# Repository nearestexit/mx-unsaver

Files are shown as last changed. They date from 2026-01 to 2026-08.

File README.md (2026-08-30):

# mx-unsaver

Custom keyboard and numpad inspired by vintage Cherry keyboards and the [IBM "Unsaver"](https://sharktastica.co.uk/topics/keyboard-dictionary/unsaver).
Designed in Onshape and KiCad.
Powered by [QMK](https://github.com/qmk/qmk_firmware).

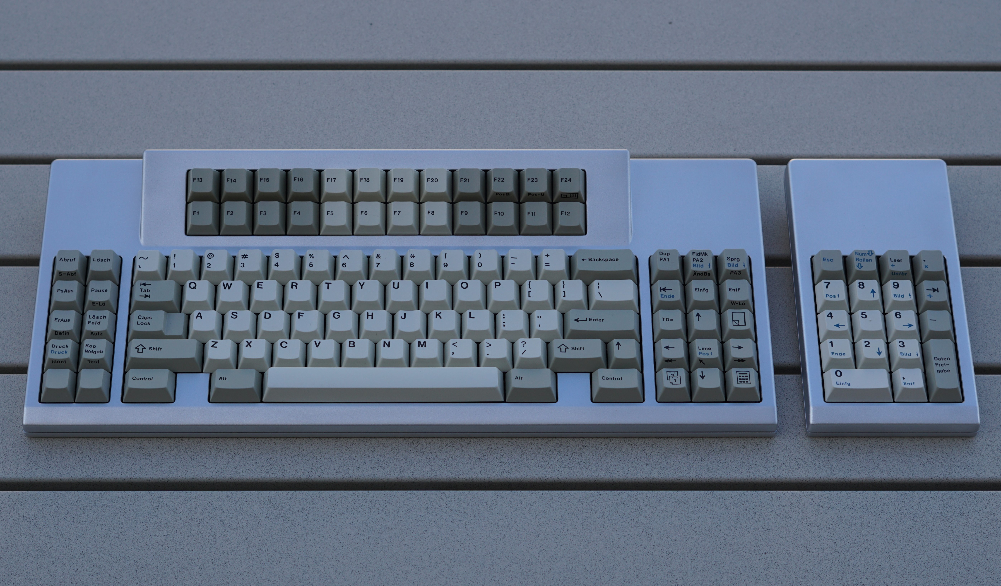
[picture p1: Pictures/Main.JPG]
Front


## Overview
- Side profile and shape inspired by the Cherry G80-5700 and G80-1800
- PCB Top-Mount
- Integrated USB Hub with 1x USB-C Upstream port and 2x USB-C and 2x USB-A Downstream ports
- Brass through-weight

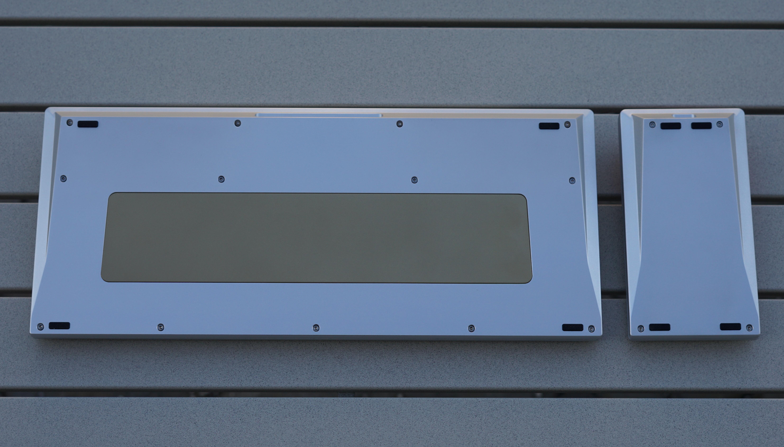
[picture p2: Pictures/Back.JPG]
Back


Combo1

**Case Source (Onshape):** https://cad.onshape.com/documents/1d9e79a61d42e7395c429f47/w/28912f958105e1c831f67a9e/e/537bd51b2d234361e6d6eea3

Combo2

## PCB
The PCB supports ISO and ANSI. Unfortunately, due to an oversight, the Case only supports ANSI enter. It could be relatively easily modified to support ISO enter.
I ordered single bare PCBs from EuroCircuits and OSHPark and hand-soldered the components, so I do not have JLCPCB production files available.

**Important: The PCB has the words "Made In Germany" printed on it. This is because it was actually manufactured in Germany. If you choose to have it manufactured in China, please remove this logo from the PCB.**

PCB

## Bill of Materials

| Item  | Quantity | Link |
| --- | --- | --- |
| M2x4x3mm Hex Standoff | 2 | https://www.ebay.com/itm/355663469861?var=624766479032 |
| M2x3x4mm Wafer head Screw | 2 | https://www.ebay.com/itm/355676691340?var=624776776427 |
| Feet | 8 | https://cannonkeys.com/products/akb-feet |
| M2.5x8mm BHCS | 57 | https://mcmaster.com/92095A459 |
| M2.5x6mm SHCS | 14 | https://mcmaster.com/91292A010 |
| M2.5x10mm SHCS | 7 | https://mcmaster.com/91292A014 |
| M2.5x25mm SHCS | 6 | https://mcmaster.com/91292A036 |
| M2.5x20mm SHCS | 4 | https://mcmaster.com/91292A019 |
| M3x6mm Countersunk | 5 | https://mcmaster.com/92125A126 |
| M3x8mm Countersunk | 9 | https://mcmaster.com/92125A128 |
| 1:1 JST-SH Cable (50mm) | 3 | https://www.digikey.com/en/products/detail/adafruit-industries-llc/4210/10230021 |
| FPC Cable (50.8mm) | 1 | https://www.digikey.com/en/products/detail/molex/0151660207/3281088 |

## USB Hub
The USB Hub utilizes two [FE1.1S](https://www.digikey.ca/datasheets/production/1879844/1/FE1-1s-Datasheet.html) USB 2.0 HS Hub chips in series. It can deliver a total of 400mA downstream (the keyboard is assumed to use 100mA).

## Firmware

A QMK .bin file is provided for flashing, as well as QMK source files.

Unsaver

(The original Unsaver in this picture is not for sale.)

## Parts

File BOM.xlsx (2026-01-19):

Item | Qty | Part number | Manufacturer | Ordered | Note
Top Case | 1 |  | Gaojie | Yes
Bottom Case | 1 |  | Gaojie | Yes
Top Case (Numpad) | 1 |  | Gaojie | Yes
Bottom Case (Numpad) | 1 |  | Gaojie | Yes
Weight | 1 |  | Gaojie | Yes
PCB Mounting Block | 19 |  | Gaojie | Yes
MCU Cover | 1 |  | Ponoko | Yes
MCU Cover Standoff | 2 | https://www.ebay.com/itm/355663469861?var=624766479032 | Ebay | Yes
MCU Cover Screw | 2 | https://www.ebay.com/itm/355676691340?var=624776776427 | Ebay | Yes
Feet | 8 | https://cannonkeys.com/products/akb-feet | Cannonkeys | Yes
PCB Screw - M2.5x8mm BHCS | 57 | 92095A459 | McMaster | Yes
DB + Hub Screw - M2.5x6mm SHCS | 14 | 91292A010 | McMaster | Yes
Case Screw - Front - M2.5x10mm SHCS | 7 | 91292A014 | McMaster | N/A
Case Screw - Back - M2.5x25mm SHCS | 6 | 91292A036 | McMaster | Yes
Case Screw - Middle - M2.5x20mm SHCS | 4 | 91292A019 | McMaster | N/A
Weight Screw - short - M3x6mm CS | 5 | 92125A126 | McMaster | N/A
Weight Screw - long - M3x8mm CS | 9 | 92125A128 | McMaster | N/A
Main PCB | 1 |  | Eurocircuits | Yes
Numpad PCB | 1 |  | Eurocircuits | Yes
F-Row PCB | 1 |  | Eurocircuits | Yes
Numpad Daughterboard | 1 |  | OSHpark | Yes
USB-A Hub PCB | 1 |  | OSHpark | Yes
USB-C Hub PCB | 1 |  | OSHpark | Yes
1:1 JST-SH Cable (50mm) | 3 |  | Digikey | Yes
Ribbon cable (50mm) | 1 |  | Digikey | Yes

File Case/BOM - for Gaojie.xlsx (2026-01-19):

Item | Quantity | Material | Surface Treatment | Color
Top Case | 1 | 6063 Aluminum | Bead blast, anodize | Silver
Bottom Case | 1 | 6063 Aluminum | Bead blast, anodize | Silver
Top Case - Numpad | 1 | 6063 Aluminum | Bead blast, anodize | Silver
Bottom Case - Numpad | 1 | 6063 Aluminum | Bead blast, anodize | Silver
Weight | 1 | Brass | Bead blast, clear coat
PCB Mount Block | 20 | Polycarbonate (PC) |  | Clear

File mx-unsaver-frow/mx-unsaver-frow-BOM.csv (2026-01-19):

Reference | Value | Datasheet | Footprint | Qty | DNP | Digikey
D1 | LED_NUM | ~ | mx-unsaver:LED_MX_3mm_Offset_Flipped | 1 |  | 67-1058-ND
D22,D23,D24,D25,D26,D42,D43,D44,D45,D46,D62,D63,D64,D65,D66,D82,D83,D84,D85,D91,D102,D103,D104,D105 | D_Small | ~ | mx-unsaver:D_SOD-123_ShiftedSilkscreen | 24 |  | 1N4148W-FDICT-ND
J2 | Conn_01x20_MountingPin | ~ | mx-unsaver:CONN-SMD_20P-P0.50_10051922-2010ELF | 1 |  | 609-10051922-2010ELFCT-ND
MX23,MX24,MX25,MX26,MX27,MX43,MX44,MX45,MX46,MX47,MX63,MX64,MX65,MX66,MX67,MX83,MX84,MX85,MX86,MX92,MX107,MX108,MX109,MX110 | MX_SW_solder | ~ | mx-unsaver:SW_MX_1u_PCBMount | 24
R1 | 1k | ~ | Resistor_SMD:R_0805_2012Metric | 1 |  | P1.0KDACT-ND

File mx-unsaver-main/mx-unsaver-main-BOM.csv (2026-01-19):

Reference | Value | Datasheet | Footprint | Qty | DNP | Digikey
C1,C2,C5,C7 | 100n | ~ | Capacitor_SMD:C_0603_1608Metric | 4 |  | 311-1088-1-ND
C3,C8,C9 | 1u | ~ | Capacitor_SMD:C_0805_2012Metric | 3 |  | 1276-1029-1-ND
C4,C6 | 4.7u | ~ | Capacitor_SMD:C_0603_1608Metric | 2 |  | 1276-1784-1-ND
D1,D2,D3,D4,D5,D6,D7,D8,D9,D10,D11,D12,D13,D14,D15,D16,D17,D18,D19,D20,D26,D27,D28,D29,D30,D31,D32,D33,D34,D35,D36,D37,D38,D46,D47,D48,D49,D50,D51,D52,D53,D54,D55,D56,D57,D58,D59,D60,D67,D68,D69,D74,D75,D76,D77,D79,D80,D81,D82,D93,D94,D95,D96,D97,D102,D103,D104,D105,D106,D107,D108,D109,D110,D112,D120,D121,D122,D123,D124,D125,D126,D127,D128,D129,D130,D131,D132,D133,D134 | D_Small | ~ | mx-unsaver:D_SOD-123_ShiftedSilkscreen | 89 |  | 1N4148W-FDICT-ND
D71 | LED_LAYER2 | ~ | mx-unsaver:LED_MX_3mm_Offset_Flipped | 1 |  | 67-1058-ND
D72 | LED_LAYER3 | ~ | mx-unsaver:LED_MX_3mm_Offset_Flipped | 1 |  | 67-1058-ND
D73 | LED_LAYER4 | ~ | mx-unsaver:LED_MX_3mm_Offset_Flipped | 1 |  | 67-1058-ND
D78 | LED_CAPS2 | ~ | mx-unsaver:LED_MX_3mm_Offset_Flipped | 1 |  | 67-1058-ND
D86 | LED_CAPS1 | ~ | mx-unsaver:LED_MX_3mm_Offset | 1 |  | 67-1058-ND
D87 | LED_LAYER5 | ~ | mx-unsaver:LED_MX_3mm_Offset_Flipped | 1 |  | 67-1058-ND
D135 | LED_NUM | ~ | mx-unsaver:LED_MX_3mm_Offset_Flipped | 1 |  | 67-1058-ND
D136 | LED_SCLK | ~ | mx-unsaver:LED_MX_3mm_Offset_Flipped | 1 |  | 67-1058-ND
D137 | LED_LAYER1 | ~ | mx-unsaver:LED_MX_3mm_Offset_Flipped | 1 |  | 67-1058-ND
G1,G2 | MadeInGermany |  | mx-unsaver:MadeInGermany | 2
J1,J2 | Conn_01x02 | ~ | mx-unsaver:PinHeader_1x02_P2.54mm_BOOT | 2
J3 | Conn_01x04_MountingPin | ~ | Connector_JST:JST_SH_SM04B-SRSS-TB_1x04-1MP_P1.00mm_Horizontal | 1 |  | 455-SM04B-SRSS-TBCT-ND
J4,J5 | Conn_01x01 | ~ | mx-unsaver:PinHeader_1x01_P2.54mm | 2
J6 | Conn_01x20_MountingPin | ~ | mx-unsaver:CONN-SMD_20P-P0.50_10051922-2010ELF | 1 |  | 609-10051922-2010ELFCT-ND
MX1,MX2,MX3,MX4,MX5,MX6,MX7,MX8,MX9,MX10,MX11,MX12,MX13,MX14,MX15,MX16,MX17,MX18,MX19,MX20,MX26,MX27,MX28,MX29,MX30,MX31,MX32,MX33,MX34,MX35,MX36,MX37,MX38,MX46,MX47,MX48,MX49,MX50,MX51,MX52,MX53,MX54,MX55,MX56,MX57,MX58,MX59,MX60,MX67,MX68,MX69,MX71,MX72,MX73,MX74,MX75,MX76,MX77,MX78,MX85,MX86,MX87,MX88,MX89,MX91,MX92,MX93,MX94,MX95,MX96,MX97,MX98,MX99,MX100,MX106,MX107,MX108,MX109,MX110,MX111,MX112,MX113,MX114,MX115,MX116,MX117,MX118,MX119,MX120,MX121,MX122,MX123,MX124,MX125,MX126,MX127 | MX_SW_solder | ~ | -- mixed values -- | 96
R1 | 10k | ~ | Resistor_SMD:R_0805_2012Metric | 1 |  | RMCF0805FT10K0CT-ND
R2,R3,R4,R6,R8,R17,R18,R19 | 1k | ~ | Resistor_SMD:R_0805_2012Metric | 8 |  | P1.0KDACT-ND
S1,S2,S3,S4,S5,S6,S7 | MX_stab |  | -- mixed values -- | 7
U1 | STM32F072CBTx | https://www.st.com/resource/en/datasheet/stm32f072cb.pdf | Package_QFP:LQFP-48_7x7mm_P0.5mm | 1
U2 | XC6206PxxxMR | https://www.torexsemi.com/file/xc6206/XC6206.pdf | Package_TO_SOT_SMD:SOT-23-3 | 1 |  | 893-XC6206P332MR-GCT-ND

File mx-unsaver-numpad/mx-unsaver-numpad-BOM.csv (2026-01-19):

Reference | Value | Datasheet | Footprint | Qty | DNP | Digikey
C1,C2,C5,C7 | 100n | ~ | Capacitor_SMD:C_0603_1608Metric | 4 |  | 311-1088-1-ND
C3,C8,C9 | 1u | ~ | Capacitor_SMD:C_0805_2012Metric | 3 |  | 1276-1029-1-ND
C4,C6 | 4.7u | ~ | Capacitor_SMD:C_0603_1608Metric | 2 |  | 1276-1784-1-ND
D1 | LED_NUM | ~ | mx-unsaver:LED_MX_3mm_Offset_Flipped | 1 |  | 67-1058-ND
J1,J2 | Conn_01x01 | ~ | mx-unsaver:PinHeader_1x01_P2.54mm | 2
J3,J4 | Conn_01x02 | ~ | mx-unsaver:PinHeader_1x02_P2.54mm_BOOT | 2
J5 | Conn_01x04_MountingPin | ~ | Connector_JST:JST_SH_SM04B-SRSS-TB_1x04-1MP_P1.00mm_Horizontal | 1 |  | 455-SM04B-SRSS-TBCT-ND
MX1,MX2,MX3,MX4,MX5,MX6,MX7,MX8,MX9,MX10,MX11,MX12,MX13,MX14,MX15,MX16,MX17,MX18,MX19,MX20,MX21,MX22,MX23 | MX_SW_solder | ~ | -- mixed values -- | 23
R1 | 10k | ~ | Resistor_SMD:R_0805_2012Metric | 1 |  | RMCF0805FT10K0CT-ND
R2 | 1k | ~ | Resistor_SMD:R_0805_2012Metric | 1 |  | P1.0KDACT-ND
S1,S2,S3 | MX_stab |  | mx-unsaver:STAB_MX_2u_FixedDistance | 3
U1 | STM32F072CBTx | https://www.st.com/resource/en/datasheet/stm32f072cb.pdf | Package_QFP:LQFP-48_7x7mm_P0.5mm | 1
U2 | XC6206PxxxMR | https://www.torexsemi.com/file/xc6206/XC6206.pdf | Package_TO_SOT_SMD:SOT-23-3 | 1 |  | 893-XC6206P332MR-GCT-ND

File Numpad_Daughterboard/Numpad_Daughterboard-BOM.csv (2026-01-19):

Reference | Value | Datasheet | Footprint | Qty | DNP | Digikey
F1 | SMD0805-050-16V | ~ | Fuse:Fuse_1206_3216Metric | 1 |  | 18-1206L050/24WRCT-ND
J1 | USB_C_Receptacle_USB2.0_16P | https://www.usb.org/sites/default/files/documents/usb_type-c.zip | mx-unsaver:PHOENIX_1332645 | 1 |  | 277-1332645CT-ND
J2 | Conn_01x04_MountingPin | ~ | Connector_JST:JST_SH_SM04B-SRSS-TB_1x04-1MP_P1.00mm_Horizontal | 1 |  | 455-SM04B-SRSS-TBCT-ND
R1,R2 | 5.1k | ~ | Capacitor_SMD:C_0603_1608Metric_Pad1.08x0.95mm_HandSolder | 2 |  | P5.10KHCT-ND
U1 | SRV05-4 | http://www.onsemi.com/pub/Collateral/SRV05-4-D.PDF | PCM_marbastlib-various:SOT-23-6-routable | 1 |  | 5399-SRV05-4CT-ND

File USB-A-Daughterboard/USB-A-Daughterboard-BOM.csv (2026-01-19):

Reference | Value | Datasheet | Footprint | Qty | DNP | Digikey
C1,C2 | 33p | ~ | Capacitor_SMD:C_0603_1608Metric | 2 |  | 1276-1070-1-ND
C3,C4,C11,C12,C13 | 100n | ~ | Capacitor_SMD:C_0603_1608Metric | 5 |  | 311-1088-1-ND
C5,C6 | 10u | ~ | Capacitor_SMD:C_0603_1608Metric | 2 |  | 1276-1192-1-ND
C7,C8 | 100u | ~ | Capacitor_SMD:C_1206_3216Metric | 2 |  | 490-GRM31CR60J107KEA8LCT-ND
C9,C10 | 1u | ~ | Capacitor_SMD:C_0603_1608Metric | 2 |  | 1276-6524-1-ND
D1,D2,D3,D4 | LED_Small | ~ | LED_SMD:LED_0603_1608Metric | 4 |  | 2007-BL-HJC36G-AV-TRBCT-ND
F1 | SMD0805-050-16V | ~ | Fuse:Fuse_1206_3216Metric | 1 |  | 18-1206L050/24WRCT-ND
J1,J2,J5 | USB_C_Receptacle_USB2.0_16P | https://www.usb.org/sites/default/files/documents/usb_type-c.zip | mx-unsaver:PHOENIX_1332645 | 3 |  | 277-1332645CT-ND
J3,J4 | Conn_01x04 | ~ | Connector_JST:JST_SH_SM04B-SRSS-TB_1x04-1MP_P1.00mm_Horizontal | 2 |  | 455-SM04B-SRSS-TBCT-ND
R1 | 2.7k | ~ | Resistor_SMD:R_0603_1608Metric | 1 |  | RMCF0603FT2K70
R2,R3,R4,R5,R10 | 10k | ~ | Resistor_SMD:R_0603_1608Metric | 5 |  | 311-10.0KHRCT-ND
R6,R7,R9 | 510 | ~ | Resistor_SMD:R_0603_1608Metric | 3 |  | RR08P510DCT-ND
R8 | 1k | ~ | Resistor_SMD:R_0603_1608Metric | 1 |  | RMCF0603FT1K00CT-ND
R11,R12 | 33k | ~ | Resistor_SMD:R_0603_1608Metric | 2 |  | 311-33.0KHRCT-ND
R13,R14 | 5.1k | ~ | Resistor_SMD:R_0603_1608Metric | 2 |  | P5.10KHCT-ND
R15,R16,R17,R18 | 56k | ~ | Resistor_SMD:R_0603_1608Metric | 4 |  | P56KGCT-ND
TP1,TP2,TP3 | TestPoint_Small | ~ | TestPoint:TestPoint_THTPad_D1.0mm_Drill0.5mm | 3
U1 | FE1.1s-BSOP28BCN | https://www.lcsc.com/datasheet/C9359.pdf | Package_SO:SSOP-28_3.9x9.9mm_P0.635mm | 1
U2,U3,U4,U5,U6 | SRV05-4 | http://www.onsemi.com/pub/Collateral/SRV05-4-D.PDF | PCM_marbastlib-various:SOT-23-6-routable | 5 |  | 5399-SRV05-4CT-ND
U7 | TPS2552DBVR |  | Package_TO_SOT_SMD:SOT-23-6 | 1
Y1 | Crystal_GND24 | ~ | Crystal:Crystal_SMD_3225-4Pin_3.2x2.5mm | 1 |  | XC1810CT-ND

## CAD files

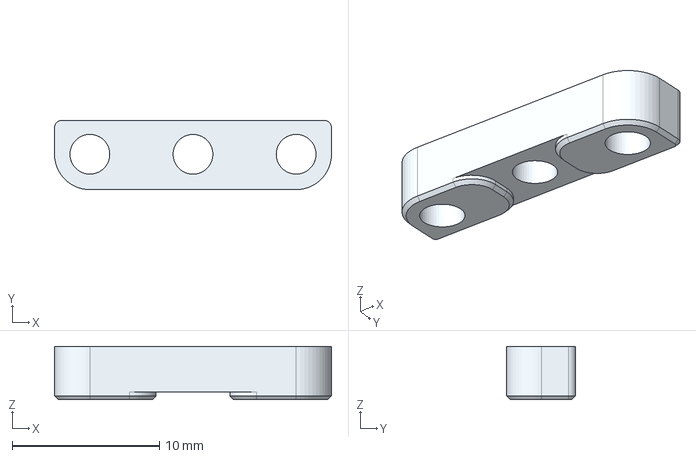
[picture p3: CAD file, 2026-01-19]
Case/STEP/PCB Mount Block.step
18.8 x 4.70 x 3.60 mm

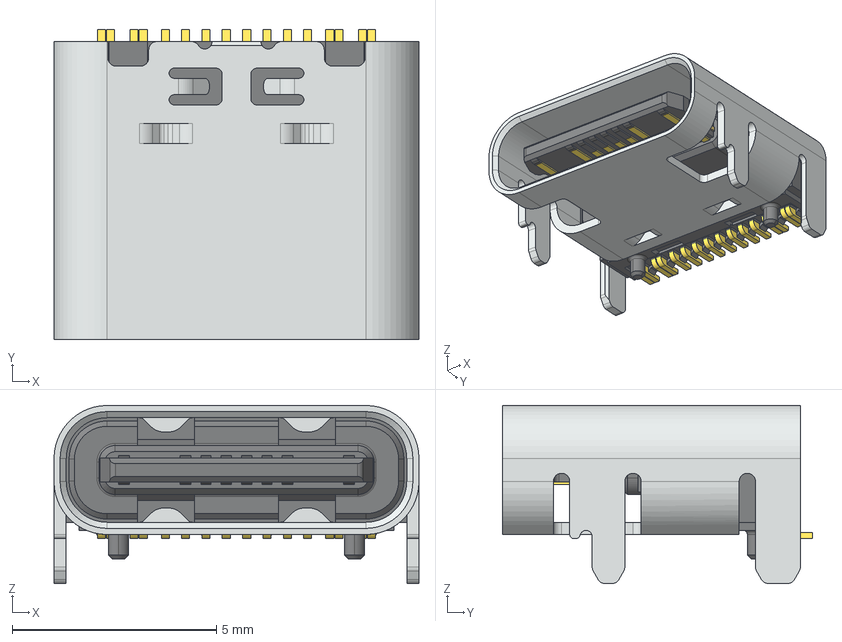
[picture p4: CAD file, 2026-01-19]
Component Datasheets & Models/pxc_1332645_00_00_CUC-USB3-1-J1ST-AH-UCF-SMD_3D.stp
8.94 x 7.60 x 4.36 mm

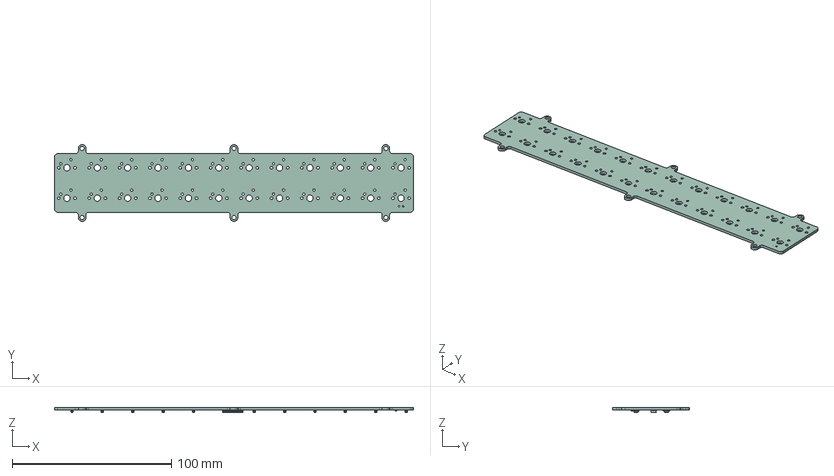
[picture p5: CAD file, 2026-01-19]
mx-unsaver-frow/mx-unsaver-frow.step
225.2 x 48.2 x 2.92 mm
D_SOD_123 x 24
R_0805_2012Metric
P10051922_2010ELF
mx-unsaver-frow_PCB

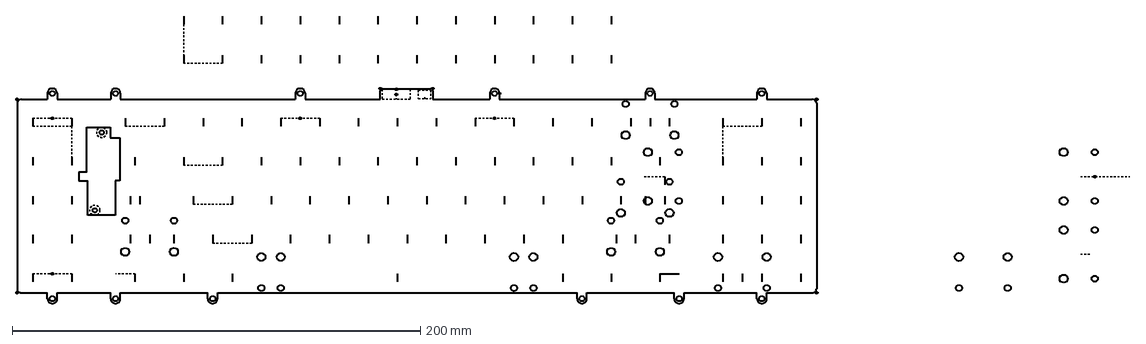
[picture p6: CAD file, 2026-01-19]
mx-unsaver-main/PCB Layout.dxf
545.9 x 140.9 mm

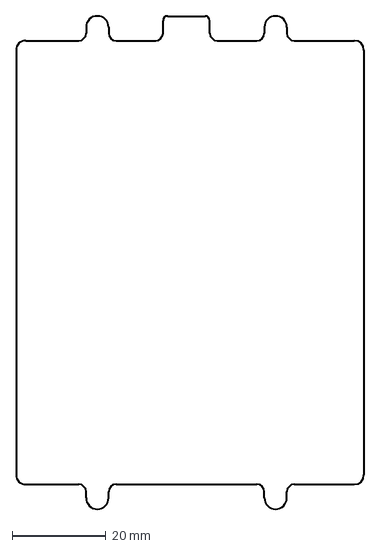
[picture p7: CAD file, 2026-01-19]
mx-unsaver-numpad/Numpad PCB Edge.cuts.dxf
74.3 x 105.4 mm

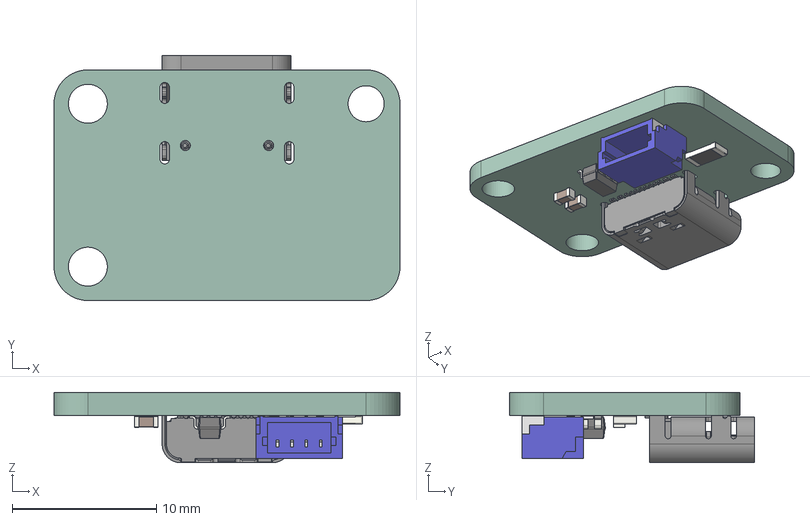
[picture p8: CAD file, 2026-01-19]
Numpad_Daughterboard/Numpad_Daughterboard.step
24.0 x 17.0 x 4.89 mm
C_0603_1608Metric x 2
CUC-USB3.1-J1ST-AH_UCF-SMD
SOT_23_6
SM04B-SRSS
Fuse_1206_3216Metric
Numpad_Daughterboard_PCB

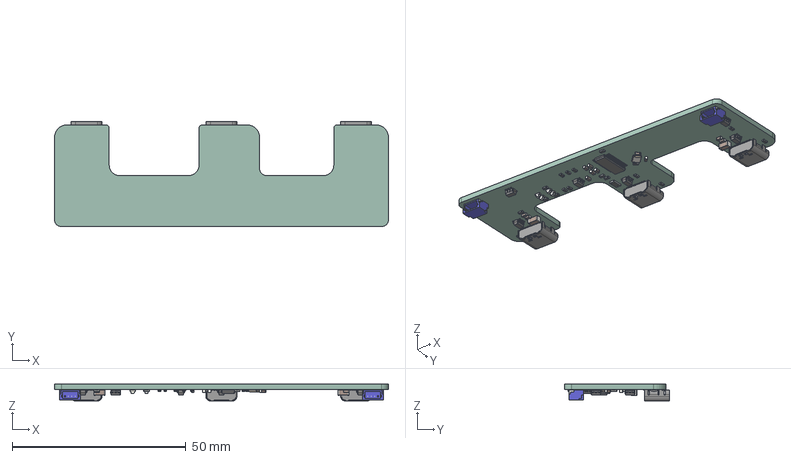
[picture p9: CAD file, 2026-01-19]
USB-A-Daughterboard/USB-A-Daughterboard.step
96.1 x 30.3 x 4.89 mm
R_0603_1608Metric x 18
SOT_23_6 x 6
SM04B-SRSS x 2
C_0603_1608Metric x 11
CUC-USB3.1-J1ST-AH_UCF-SMD x 3
C_1206_3216Metric x 2
Fuse_1206_3216Metric
SSOP_28_39x99mm_P0635mm
LED_0603_1608Metric x 4
Crystal_SMD_3225-4Pin_3.2x2.5mm
USB-A-Daughterboard_PCB

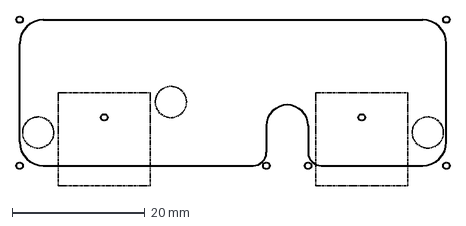
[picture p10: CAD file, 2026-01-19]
USBHubV3/USB-A PCB Layout.dxf
65.3 x 25.5 mm

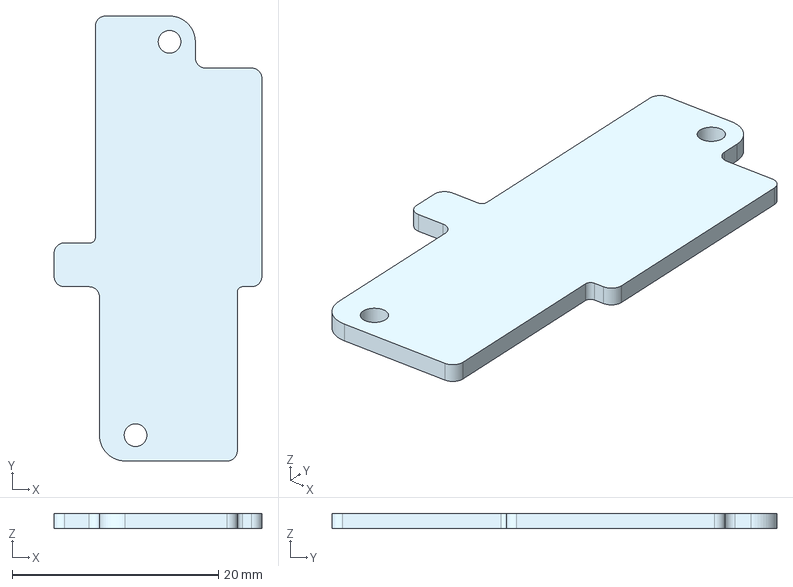
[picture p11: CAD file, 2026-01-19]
Case/STEP/MCU Cover.step
20.2 x 43.1 x 1.50 mm

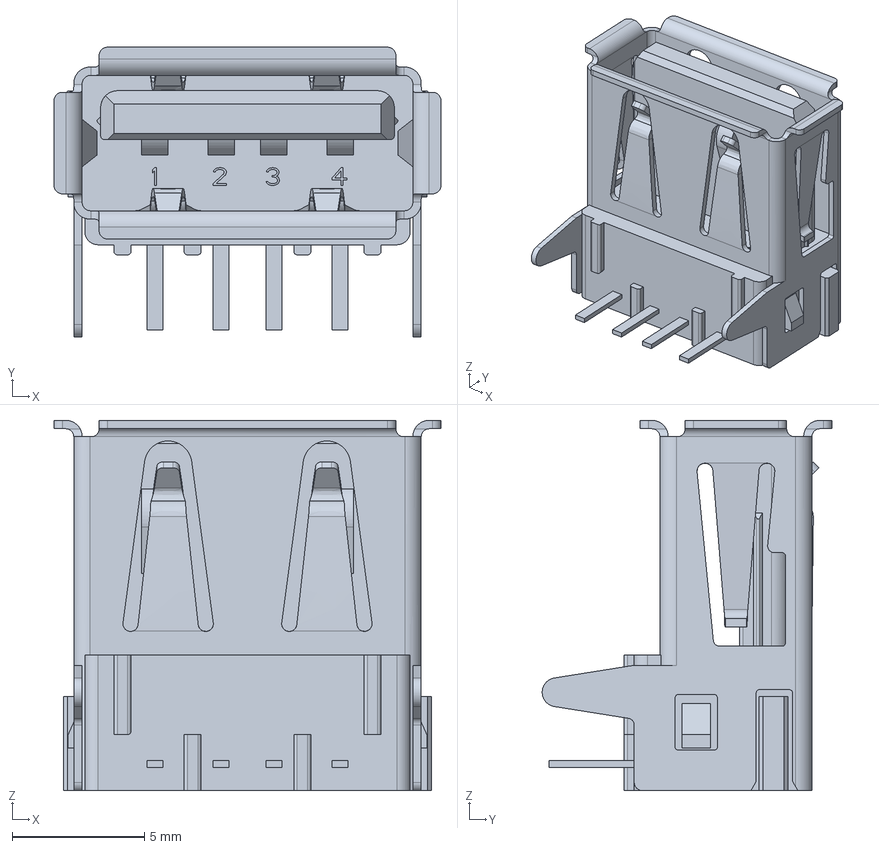
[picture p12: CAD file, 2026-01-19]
Component Datasheets & Models/c-6364372-2-o-3d.stp
14.6 x 10.9 x 14.0 mm

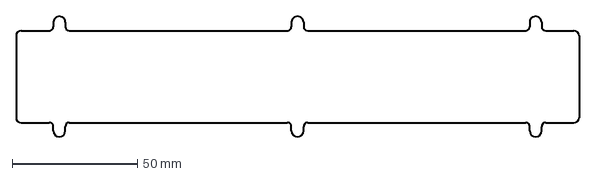
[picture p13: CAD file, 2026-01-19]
mx-unsaver-frow/F-Row PCB Edge.Cuts.dxf
225.2 x 48.3 mm

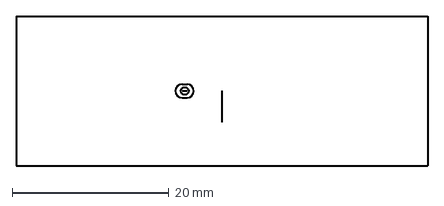
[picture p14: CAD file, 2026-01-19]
mx-unsaver-main/Drawing - RShift.dxf
52.4 x 19.0 mm

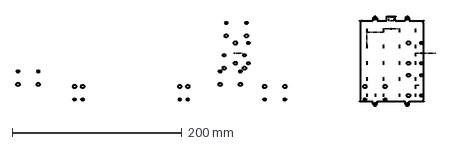
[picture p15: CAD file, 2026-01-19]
mx-unsaver-numpad/Numpad PCB Layout.dxf
494.1 x 106.0 mm

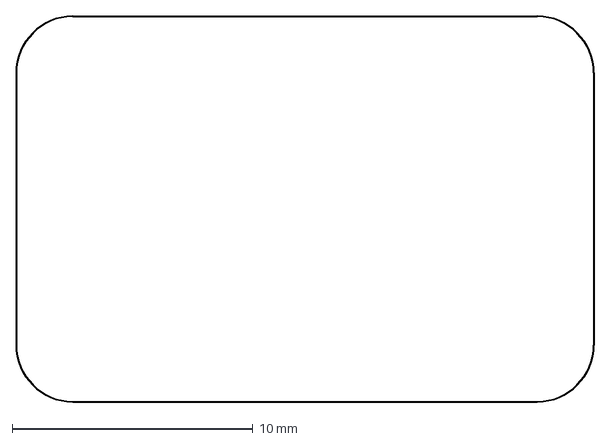
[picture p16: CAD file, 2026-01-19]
Numpad_Daughterboard/Numpad DB Edge.Cuts.dxf
24.0 x 16.0 mm

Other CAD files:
USBHubV3/USBHubV3.step
Case/STEP/Bottom Case.step
mx-unsaver-frow/F-Row PCB Layout.dxf
mx-unsaver-main/Drawing - LShift.dxf
Case/STEP/Bottom Case - Numpad.step
Case/STEP/Top Case - Numpad.step
Case/STEP/Top Case.step
Case/STEP/Weight.step
Numpad_Daughterboard/Numpad DB Layout.dxf
USBHubV3/USB-A PCB Edge.Cuts.dxf
mx-unsaver-main/Drawing - Enter.dxf
mx-unsaver-main/Drawing - Split Backspace Slots.dxf
mx-unsaver-main/PCB Edge.cuts.dxf
mx-unsaver-numpad/mx-unsaver-numpad.step

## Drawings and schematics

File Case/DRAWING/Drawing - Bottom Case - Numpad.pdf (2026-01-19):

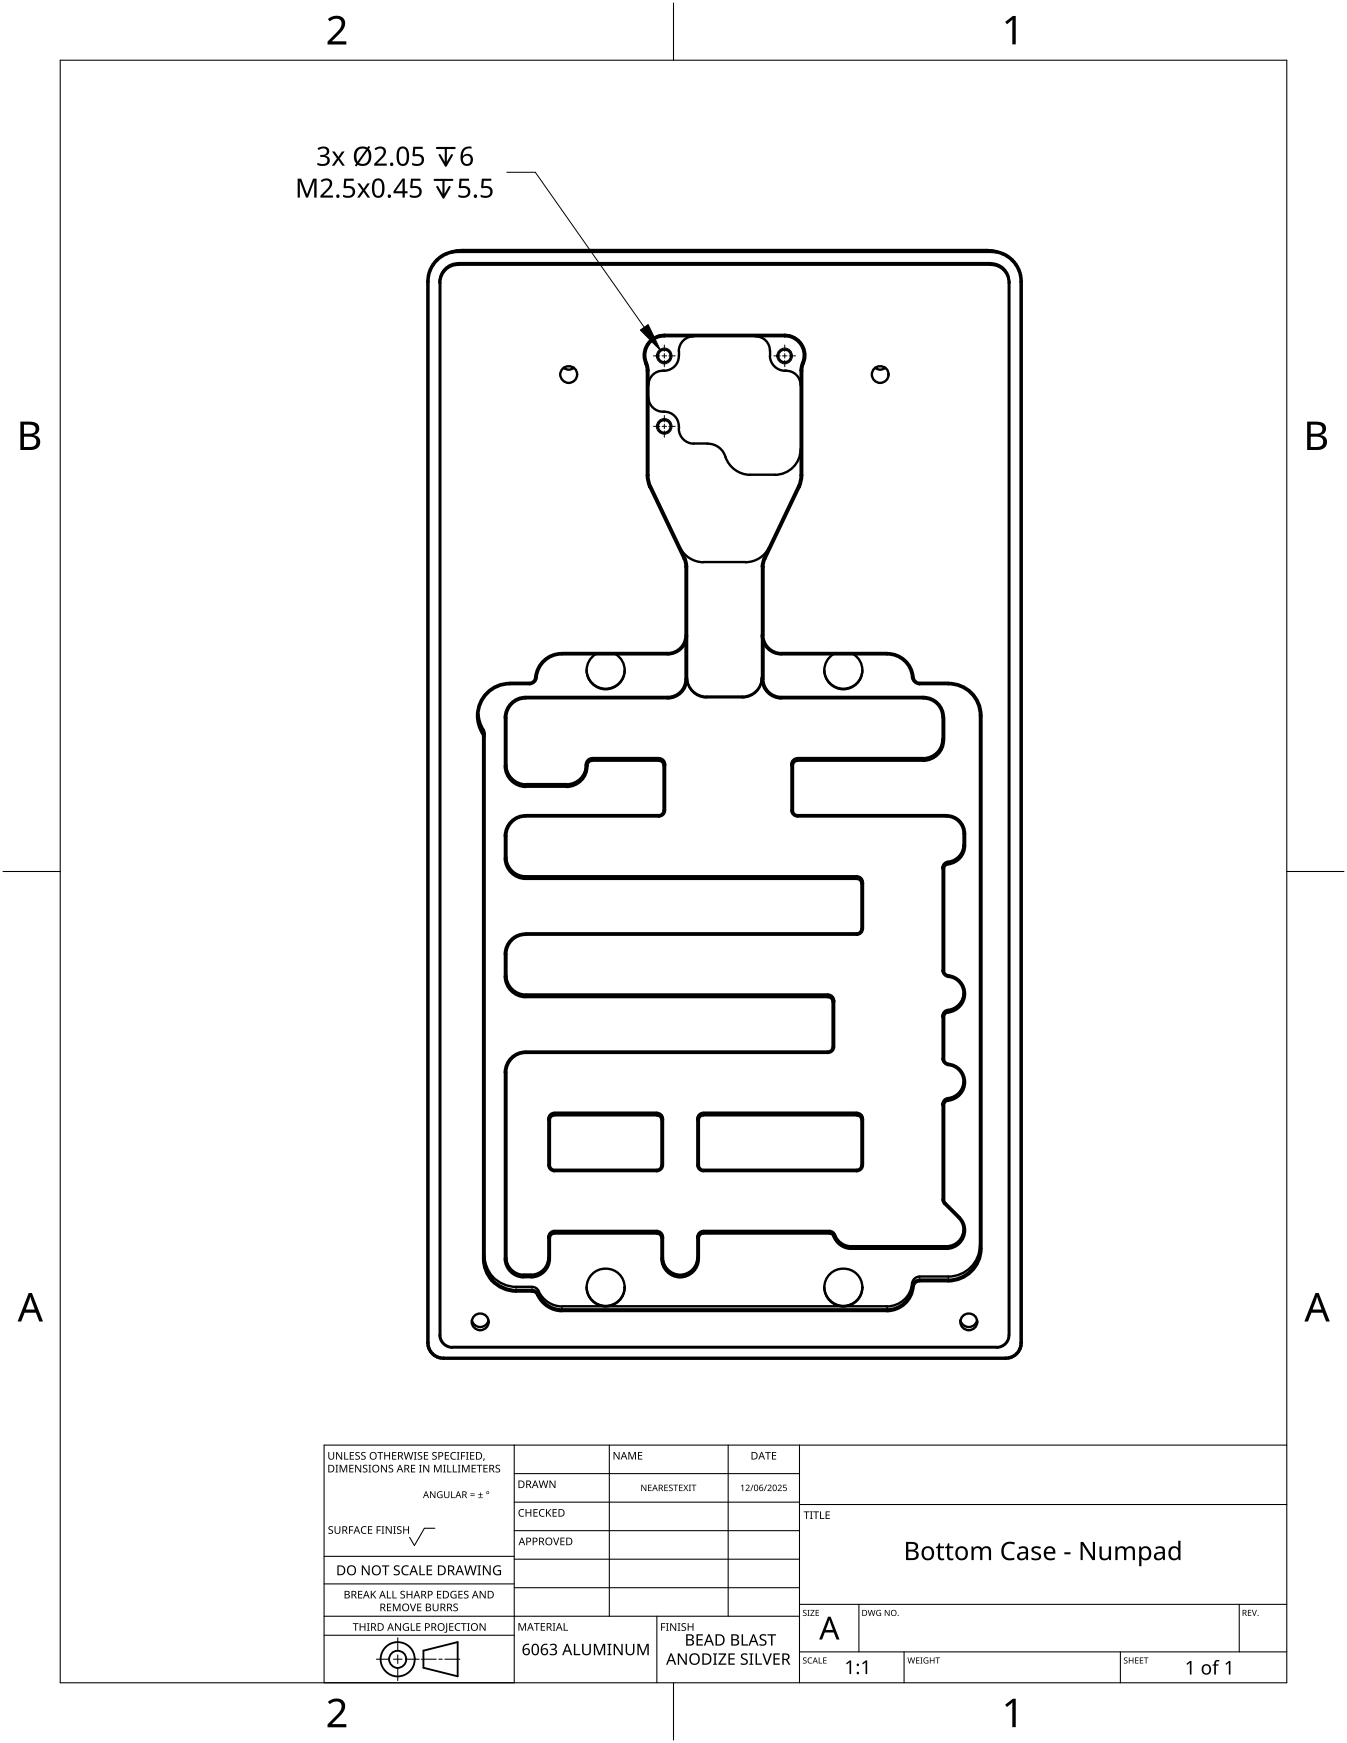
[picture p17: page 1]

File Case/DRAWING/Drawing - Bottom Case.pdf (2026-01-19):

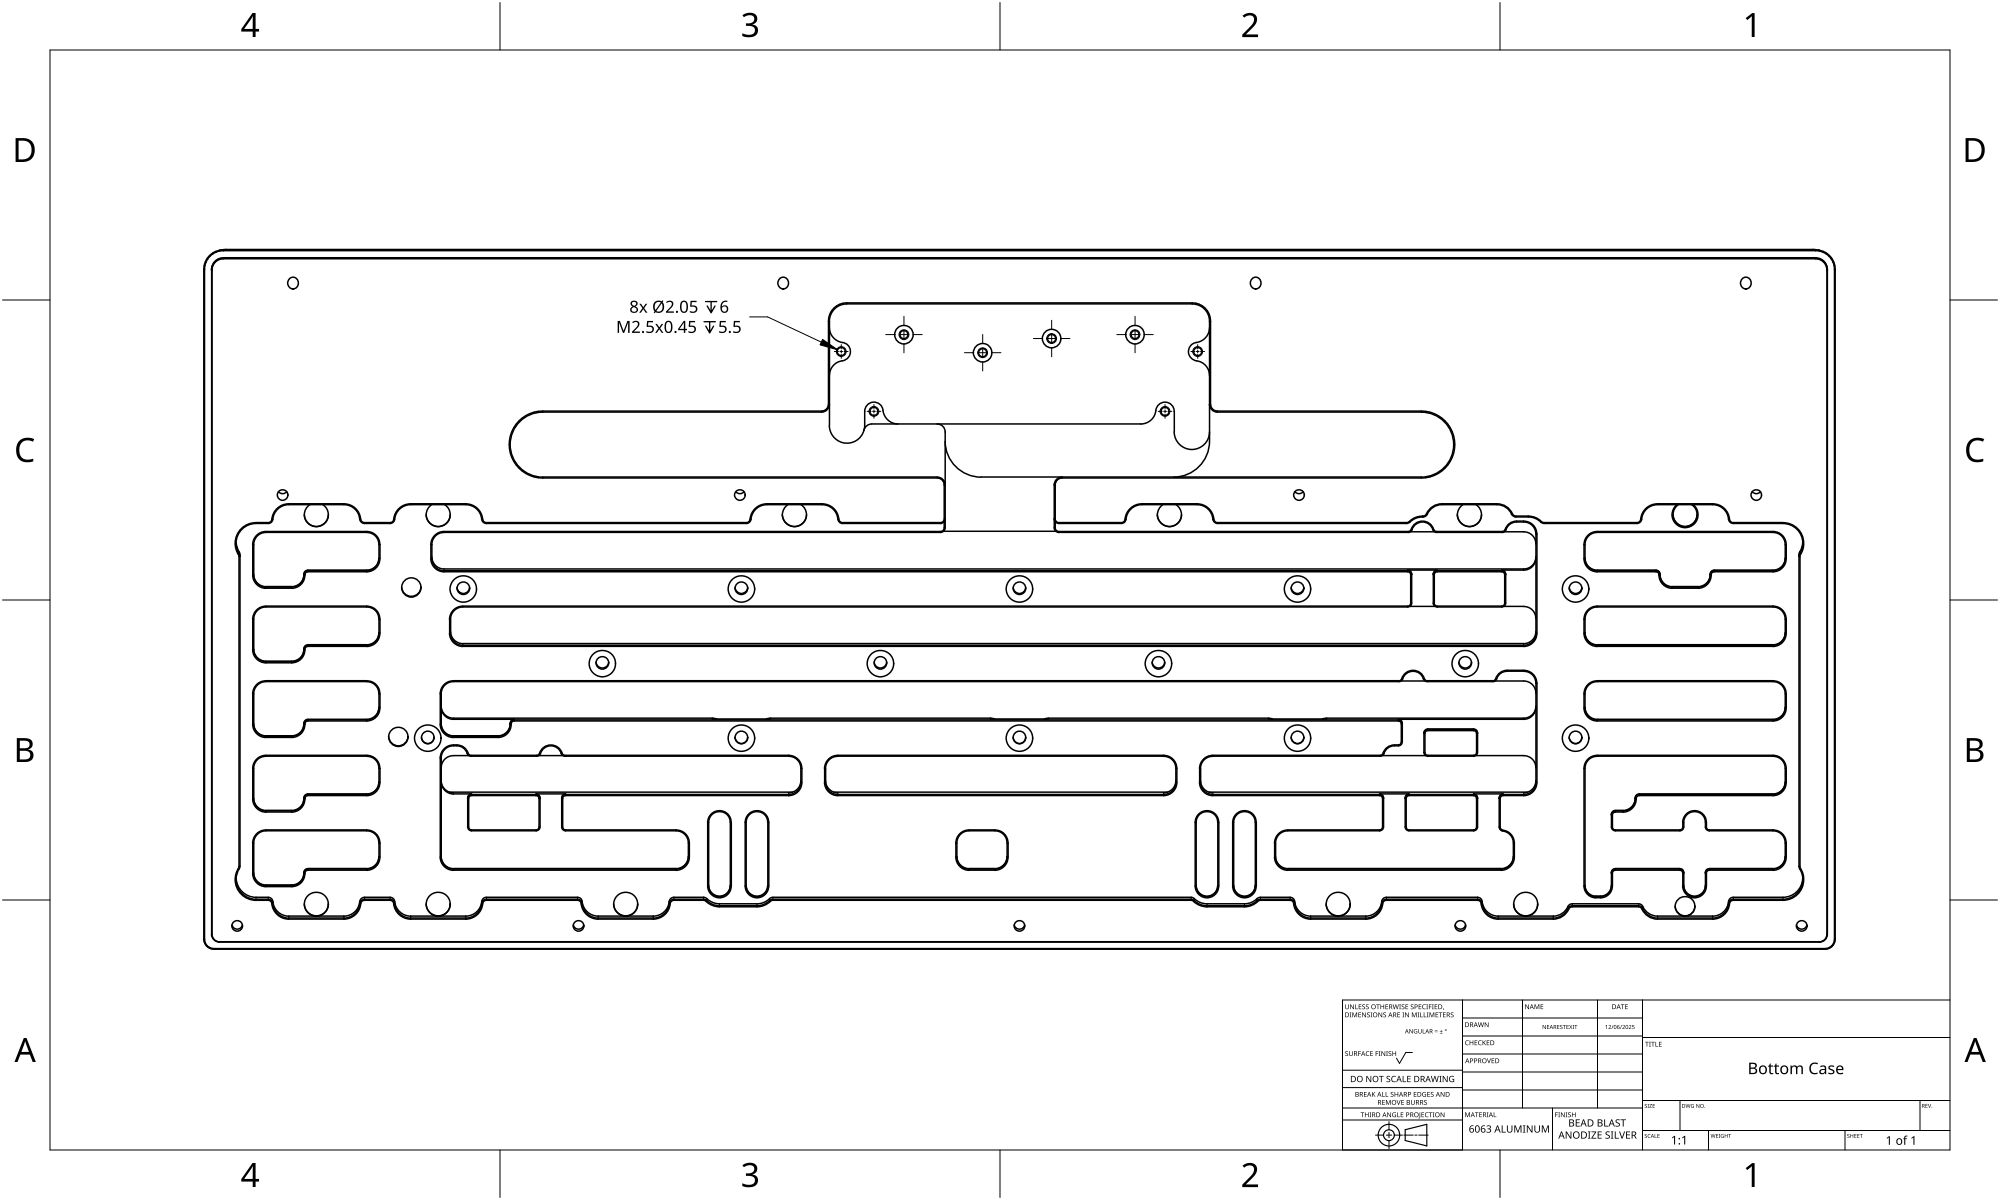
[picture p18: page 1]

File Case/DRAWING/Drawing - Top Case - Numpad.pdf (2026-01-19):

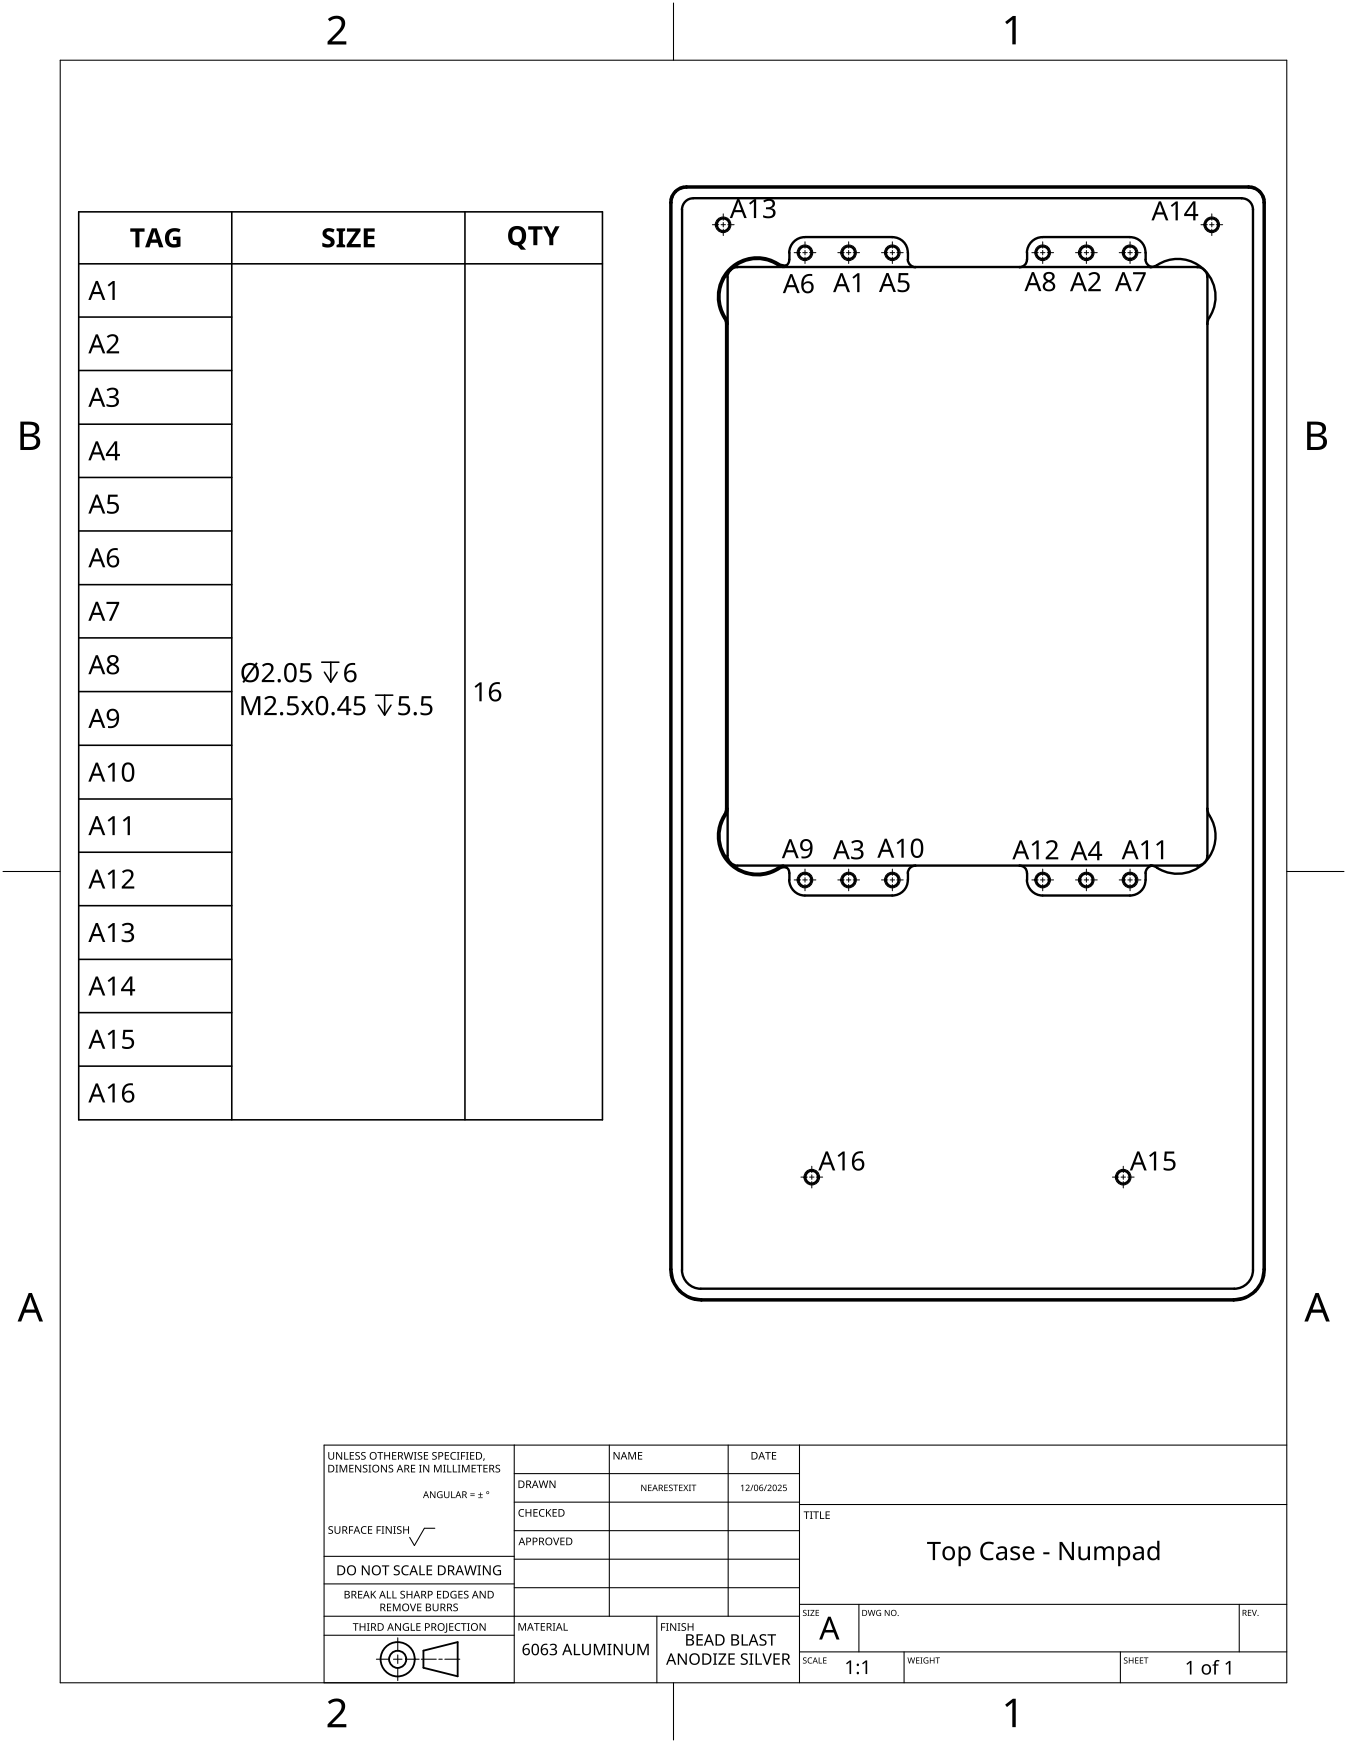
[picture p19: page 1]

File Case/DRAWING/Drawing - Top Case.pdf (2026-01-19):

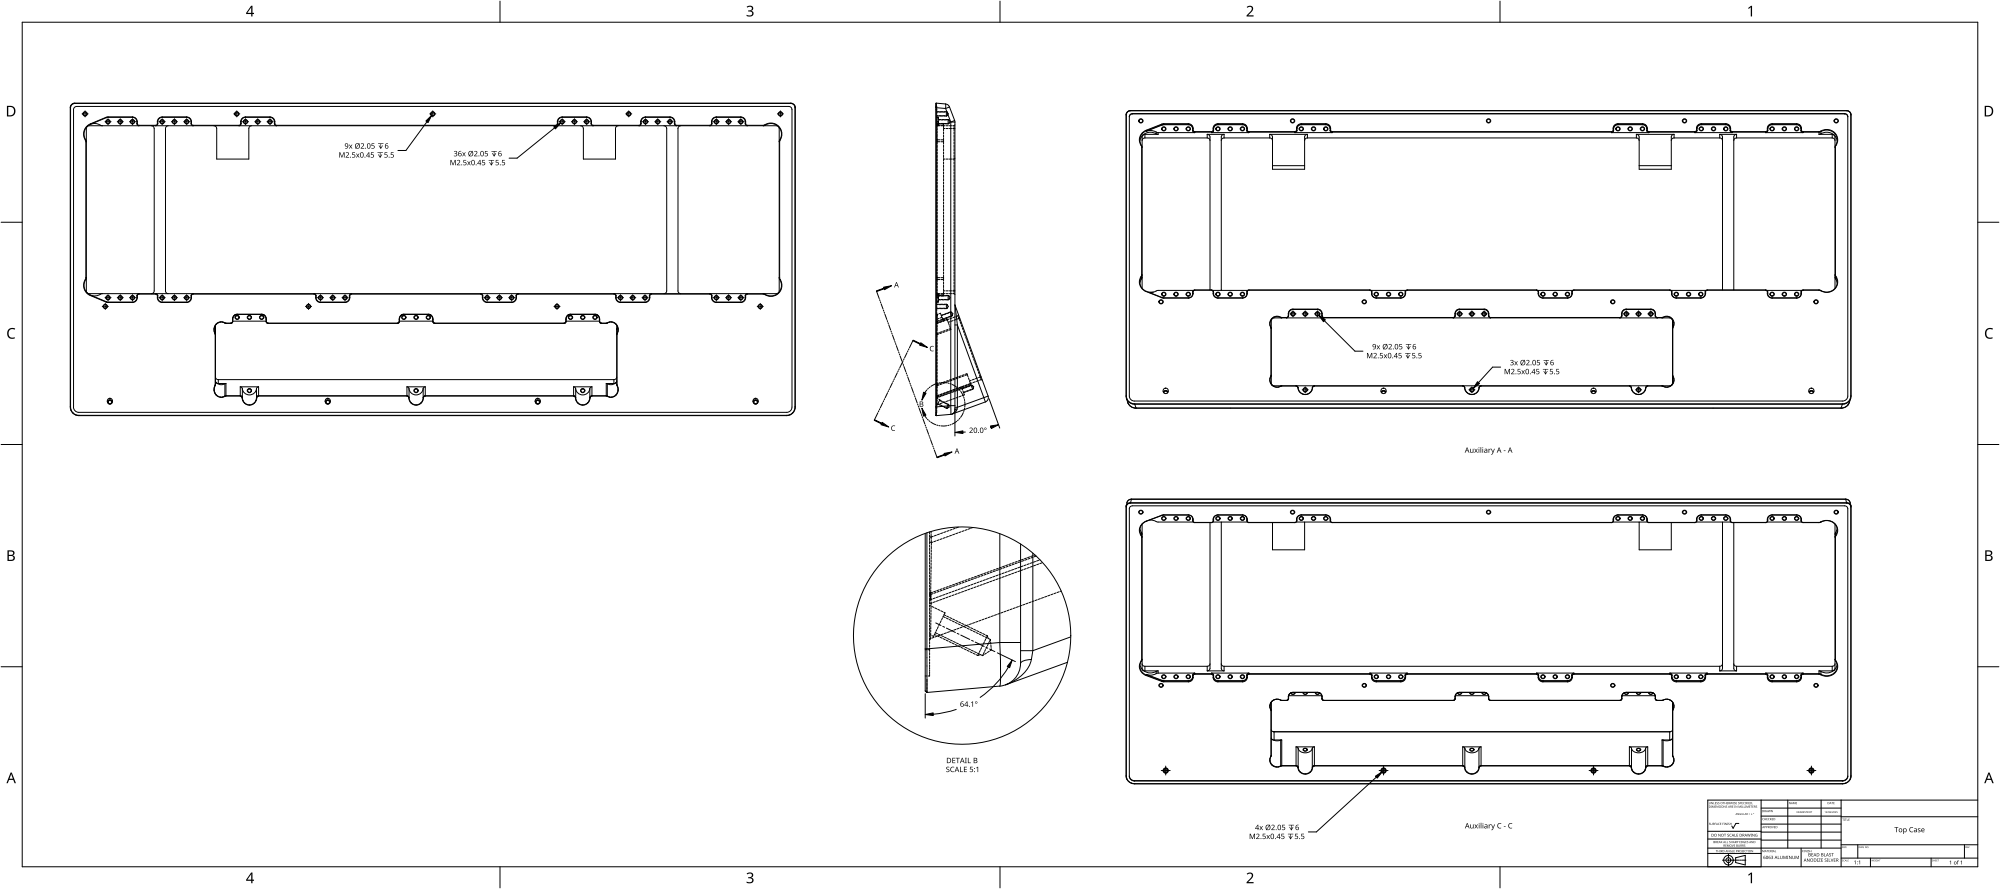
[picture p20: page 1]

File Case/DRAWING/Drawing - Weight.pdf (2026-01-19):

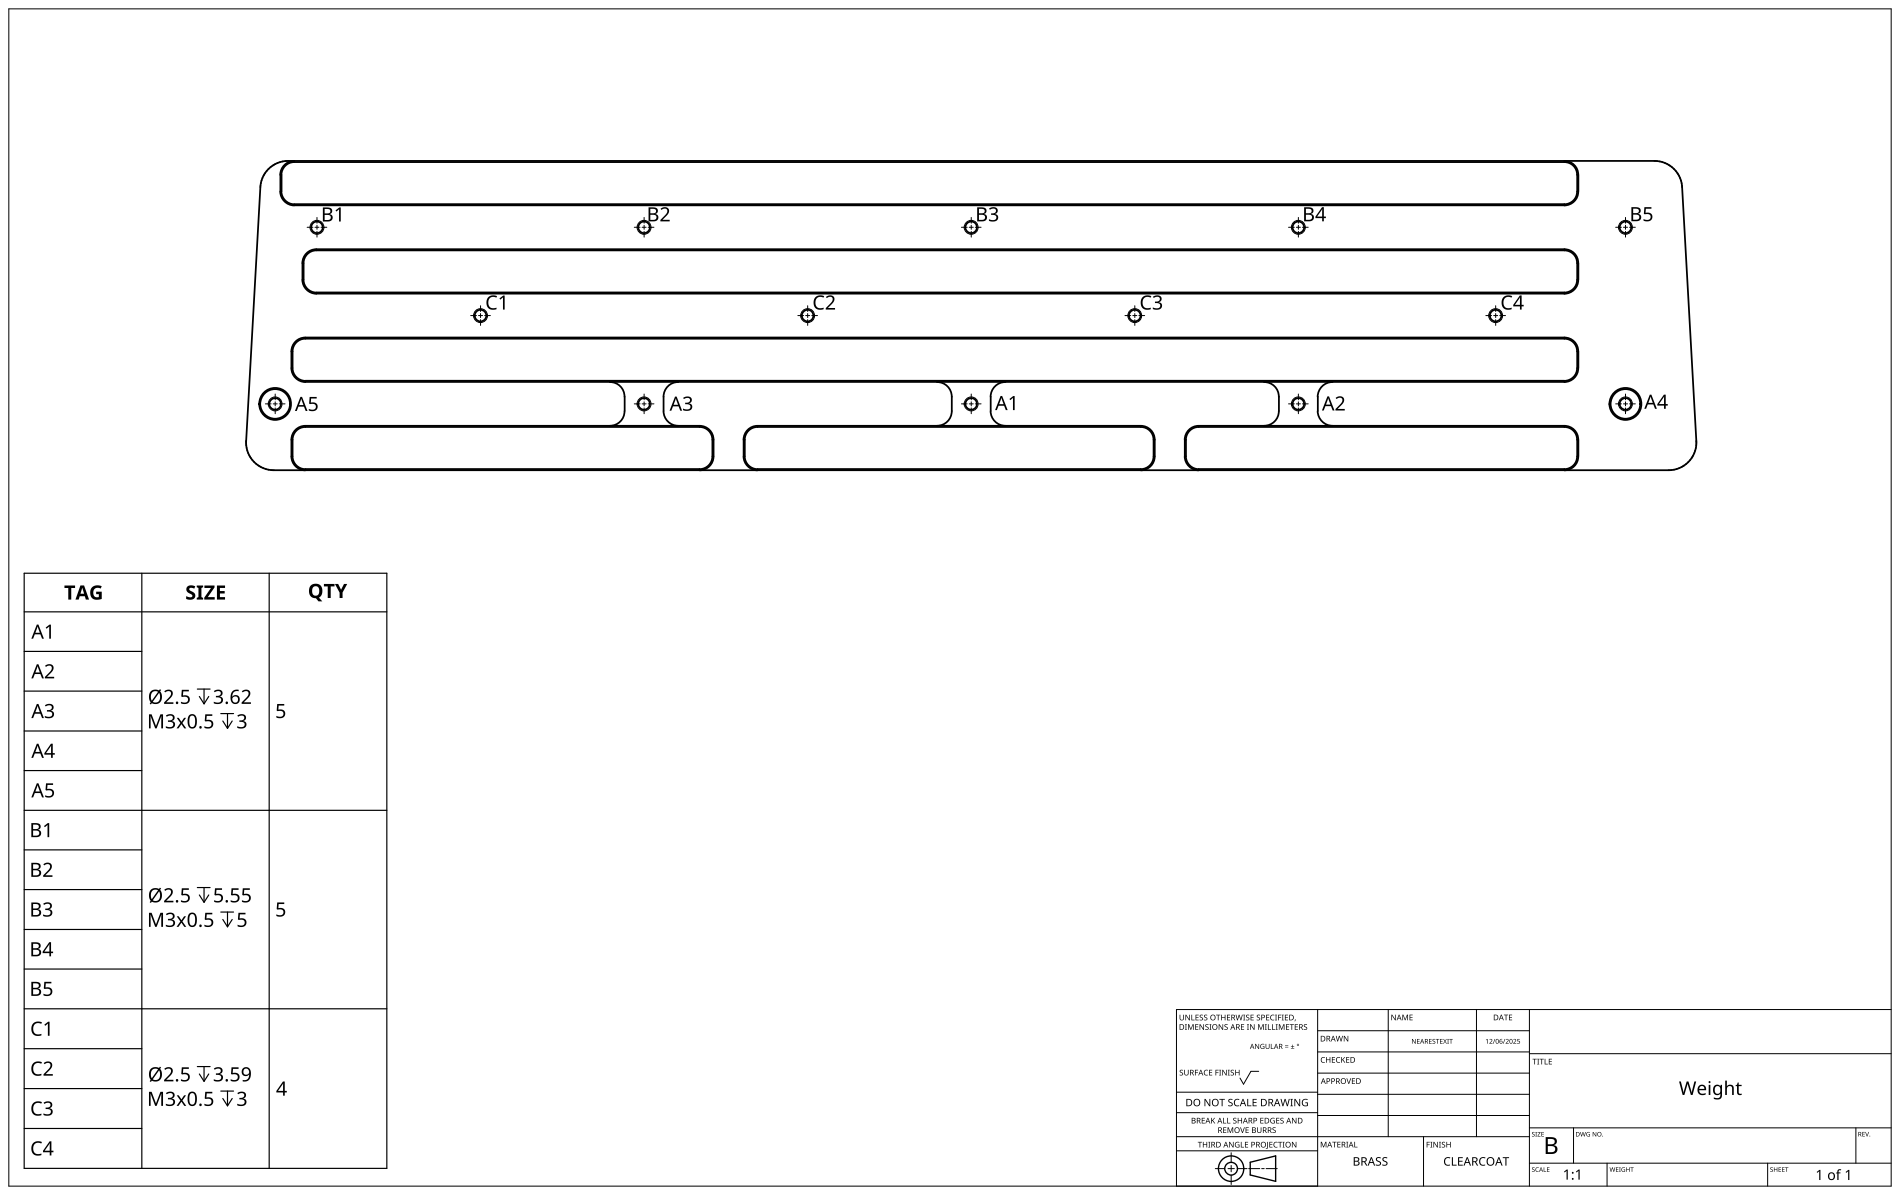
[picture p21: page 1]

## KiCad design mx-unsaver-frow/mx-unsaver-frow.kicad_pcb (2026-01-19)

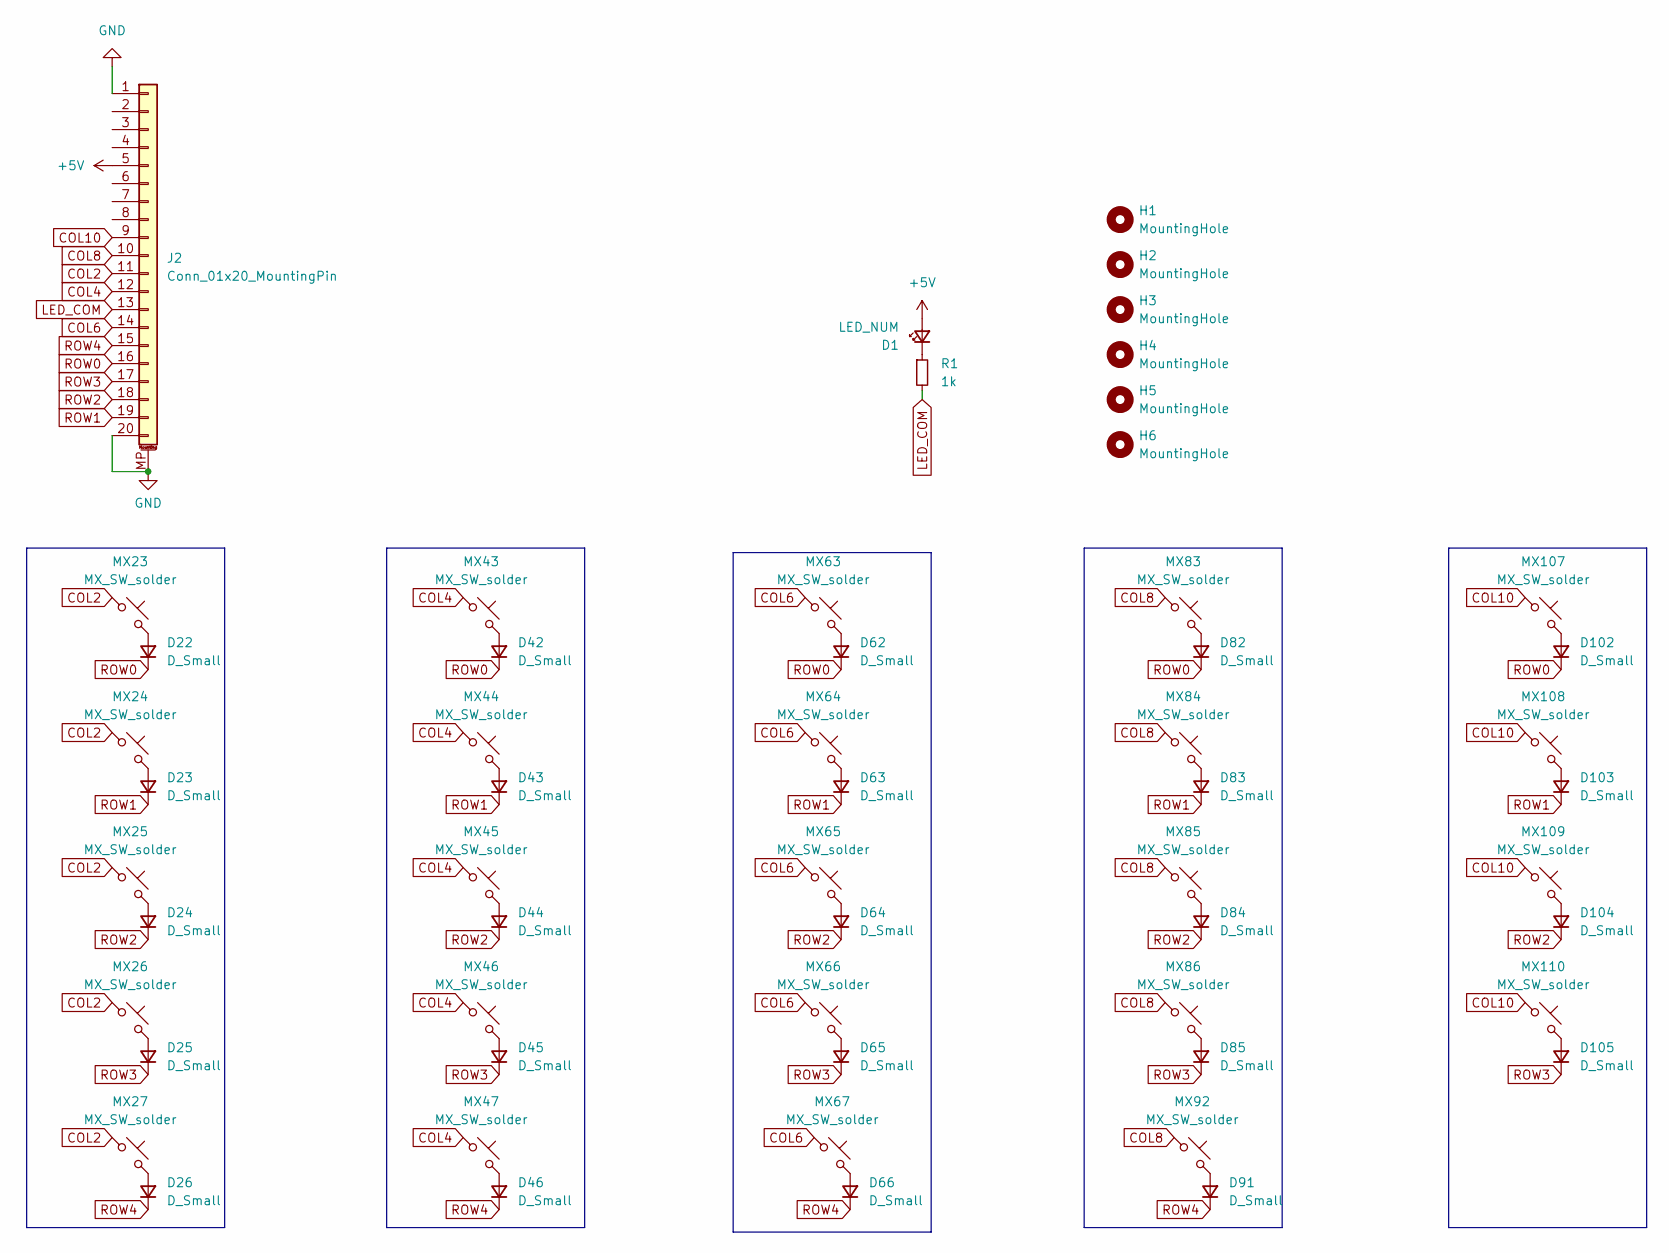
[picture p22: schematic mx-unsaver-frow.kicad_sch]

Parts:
D1: LED_NUM; LED_MX_3mm_Offset_Flipped; Digikey 67-1058-ND
D22, D23, D24, D25, D26, D42, D43, D44, D45, D46, D62, D63, D64, D65, D66, D82, D83, D84, D85, D91, D102, D103, D104, D105: D_Small; D_SOD-123_ShiftedSilkscreen; Digikey 1N4148W-FDICT-ND
H1, H2, H3, H4, H5, H6: MountingHole; MountingHole_2.7mm_M2.5
J2: Conn_01x20_MountingPin; CONN-SMD_20P-P0.50_10051922-2010ELF; Digikey 609-10051922-2010ELFCT-ND
MX23, MX24, MX25, MX26, MX27, MX43, MX44, MX45, MX46, MX47, MX63, MX64, MX65, MX66, MX67, MX83, MX84, MX85, MX86, MX92, MX107, MX108, MX109, MX110: MX_SW_solder; SW_MX_1u_PCBMount
R1: 1k; R_0805_2012Metric; Digikey P1.0KDACT-ND

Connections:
+5V: D1.2 (A), J2.5
COL2: J2.11, MX23.1, MX24.1, MX25.1, MX26.1, MX27.1
COL4: J2.12, MX43.1, MX44.1, MX45.1, MX46.1, MX47.1
COL6: J2.14, MX63.1, MX64.1, MX65.1, MX66.1, MX67.1
COL8: J2.10, MX83.1, MX84.1, MX85.1, MX86.1, MX92.1
COL10: J2.9, MX107.1, MX108.1, MX109.1, MX110.1
GND: J2.1, J2.20, J2.MP (MountPin)
LED_COM: J2.13, R1.2
unnamed: D1.1 (K), R1.1
unnamed: D22.2 (A), MX23.2
unnamed: D23.2 (A), MX24.2
unnamed: D24.2 (A), MX25.2
unnamed: D25.2 (A), MX26.2
unnamed: D26.2 (A), MX27.2
unnamed: D42.2 (A), MX43.2
unnamed: D43.2 (A), MX44.2
unnamed: D44.2 (A), MX45.2
unnamed: D45.2 (A), MX46.2
unnamed: D46.2 (A), MX47.2
unnamed: D62.2 (A), MX63.2
unnamed: D63.2 (A), MX64.2
unnamed: D64.2 (A), MX65.2
unnamed: D65.2 (A), MX66.2
unnamed: D66.2 (A), MX67.2
unnamed: D82.2 (A), MX83.2
unnamed: D83.2 (A), MX84.2
unnamed: D84.2 (A), MX85.2
unnamed: D85.2 (A), MX86.2
unnamed: D91.2 (A), MX92.2
unnamed: D102.2 (A), MX107.2
unnamed: D103.2 (A), MX108.2
unnamed: D104.2 (A), MX109.2
unnamed: D105.2 (A), MX110.2
ROW0: D22.1 (K), D42.1 (K), D62.1 (K), D82.1 (K), D102.1 (K), J2.16
ROW1: D23.1 (K), D43.1 (K), D63.1 (K), D83.1 (K), D103.1 (K), J2.19
ROW2: D24.1 (K), D44.1 (K), D64.1 (K), D84.1 (K), D104.1 (K), J2.18
ROW3: D25.1 (K), D45.1 (K), D65.1 (K), D85.1 (K), D105.1 (K), J2.17
ROW4: D26.1 (K), D46.1 (K), D66.1 (K), D91.1 (K), J2.15

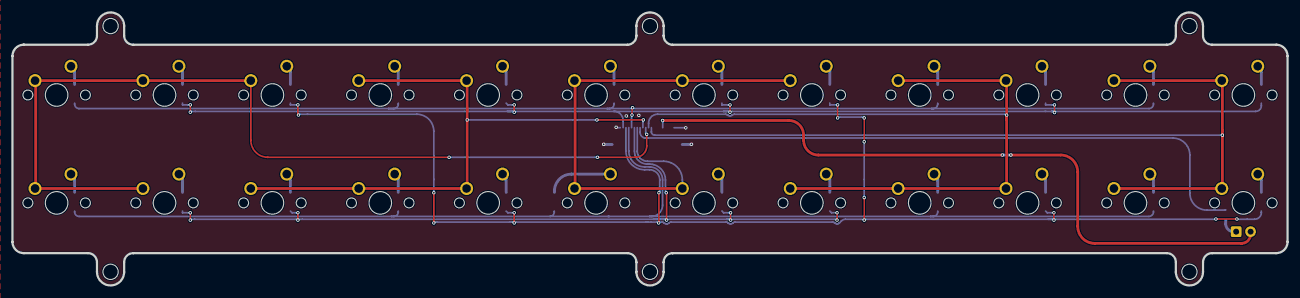
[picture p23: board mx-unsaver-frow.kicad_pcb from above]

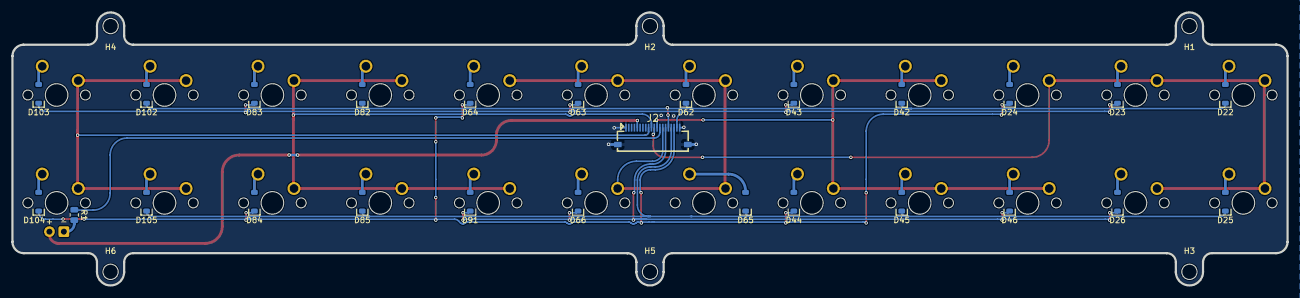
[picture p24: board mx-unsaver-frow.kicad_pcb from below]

Board: 2 copper layers, 225.2 x 48.2 mm, 57 parts (33 on the bottom side), 38 nets.

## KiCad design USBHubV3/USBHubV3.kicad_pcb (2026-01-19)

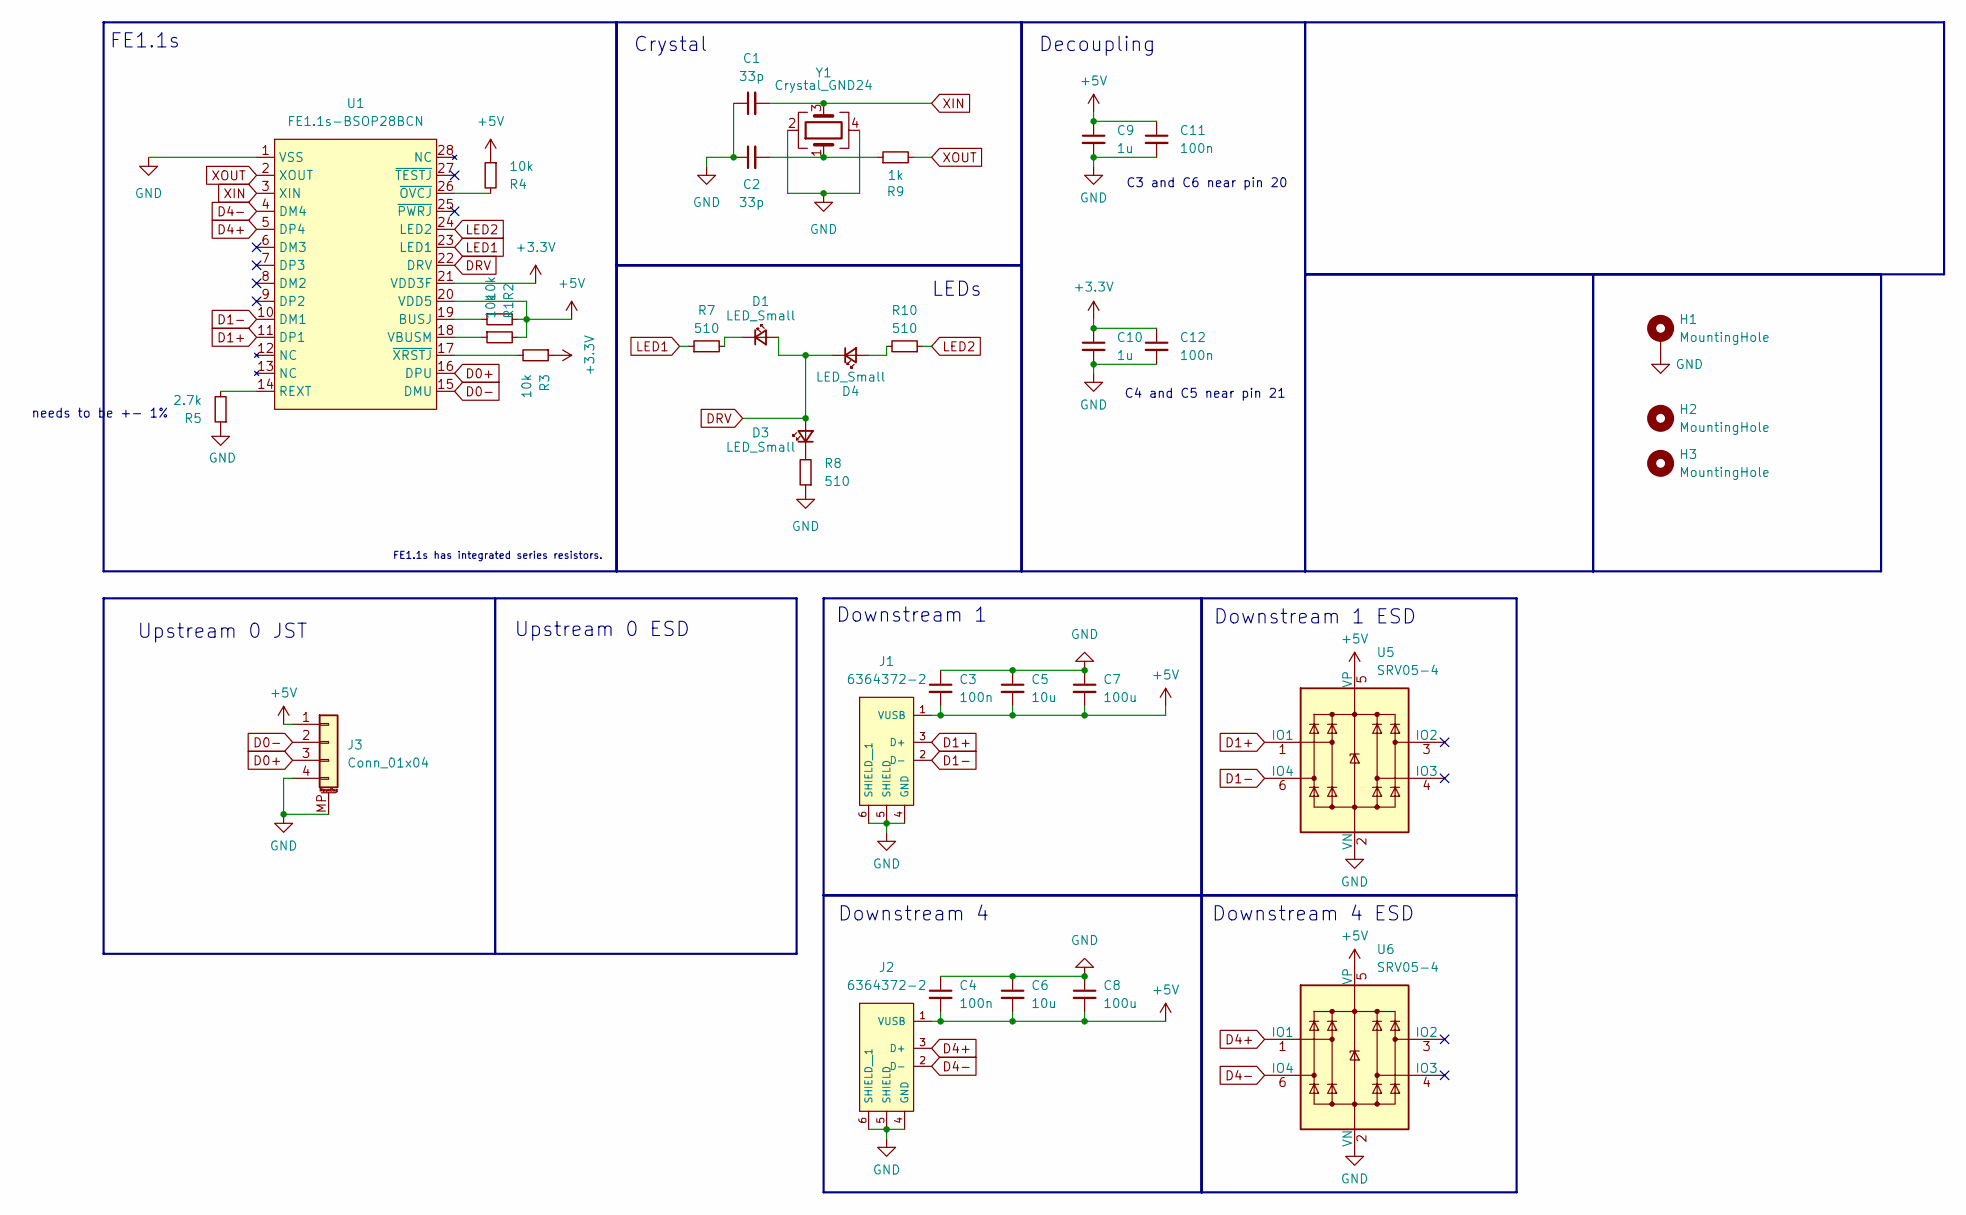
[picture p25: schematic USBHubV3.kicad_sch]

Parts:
C1, C2: 33p; C_0603_1608Metric; Digikey 1276-1070-1-ND
C3, C4, C11, C12: 100n; C_0603_1608Metric; Digikey 311-1088-1-ND
C5, C6: 10u; C_0603_1608Metric; Digikey 1276-1192-1-ND
C7, C8: 100u; C_1206_3216Metric; Digikey 490-GRM31CR60J107KEA8LCT-ND
C9, C10: 1u; C_0603_1608Metric; Digikey 1276-6524-1-ND
D1, D3, D4: LED_Small; LED_0603_1608Metric; Digikey 2007-BL-HJC36G-AV-TRBCT-ND
H1: MountingHole; MountingHole_2.7mm_M2.5_DIN965_Pad
H2, H3: MountingHole; MountingHole_2.7mm_M2.5
J1, J2: 6364372-2; TE_6364372-2; Digikey A122647-ND
J3: Conn_01x04; JST_SH_SM04B-SRSS-TB_1x04-1MP_P1.00mm_Horizontal; Digikey 455-SM04B-SRSS-TBCT-ND
R1, R2, R3, R4: 10k; R_0603_1608Metric; Digikey 311-10.0KHRCT-ND
R5: 2.7k; R_0603_1608Metric; Digikey RMCF0603FT2K70CT-ND
R7, R8, R10: 510; R_0603_1608Metric; Digikey RR08P510DCT-ND
R9: 1k; R_0603_1608Metric; Digikey RMCF0603FT1K00CT-ND
U1: FE1.1s-BSOP28BCN; SSOP-28_3.9x9.9mm_P0.635mm
U5, U6: SRV05-4; SOT-23-6-routable; Digikey 5399-SRV05-4CT-ND
Y1: Crystal_GND24; Crystal_SMD_3225-4Pin_3.2x2.5mm; Digikey XC1810CT-ND

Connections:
+3.3V: C10.1, C12.1, R3.1, U1.21 (VDD3F)
+5V: C3.2, C4.2, C5.2, C6.2, C7.2, C8.2, C9.1, C11.1, J1.1 (VUSB), J2.1 (VUSB), J3.1, R1.2, R2.2, R4.1, U1.20 (VDD5), U5.5 (VP), U6.5 (VP)
D0+: J3.3, U1.16 (DPU)
D0-: J3.2, U1.15 (DMU)
D1+: J1.3 (D+), U1.11 (DP1), U5.1 (IO1)
D1-: J1.2 (D-), U1.10 (DM1), U5.6 (IO4)
D4+: J2.3 (D+), U1.5 (DP4), U6.1 (IO1)
D4-: J2.2 (D-), U1.4 (DM4), U6.6 (IO4)
DRV: D1.2 (A), D3.2 (A), D4.1 (K), U1.22 (DRV)
GND: C1.1, C2.1, C3.1, C4.1, C5.1, C6.1, C7.1, C8.1, C9.2, C10.2, C11.2, C12.2, H1.1, J1.4 (GND), J1.5 (SHIELD), J1.6 (SHIELD__1), J2.4 (GND), J2.5 (SHIELD), J2.6 (SHIELD__1), J3.4, J3.MP (MountPin), R5.1, R8.1, U1.1 (VSS), U5.2 (VN), U6.2 (VN), Y1.2, Y1.4
LED1: R7.1, U1.23 (LED1)
LED2: R10.1, U1.24 (LED2)
unnamed: C2.2, R9.1, Y1.1
unnamed: D1.1 (K), R7.2
unnamed: D3.1 (K), R8.2
unnamed: D4.2 (A), R10.2
unnamed: R2.1, U1.19 (BUSJ)
unnamed: R5.2, U1.14 (REXT)
unnamed: R1.1, U1.18 (VBUSM)
unnamed: R4.2, U1.26 (~OVCJ)
unnamed: R3.2, U1.17 (~XRSTJ)
XIN: C1.2, U1.3 (XIN), Y1.3
XOUT: R9.2, U1.2 (XOUT)

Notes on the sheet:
Upstream 0 JST
Decoupling
Upstream 0 ESD
Downstream 4
FE1.1s
C4 and C5 near pin 21
FE1.1s has integrated series resistors.
LEDs
Downstream 1
Downstream 1 ESD
C3 and C6 near pin 20
Crystal
needs to be +- 1%
Downstream 4 ESD

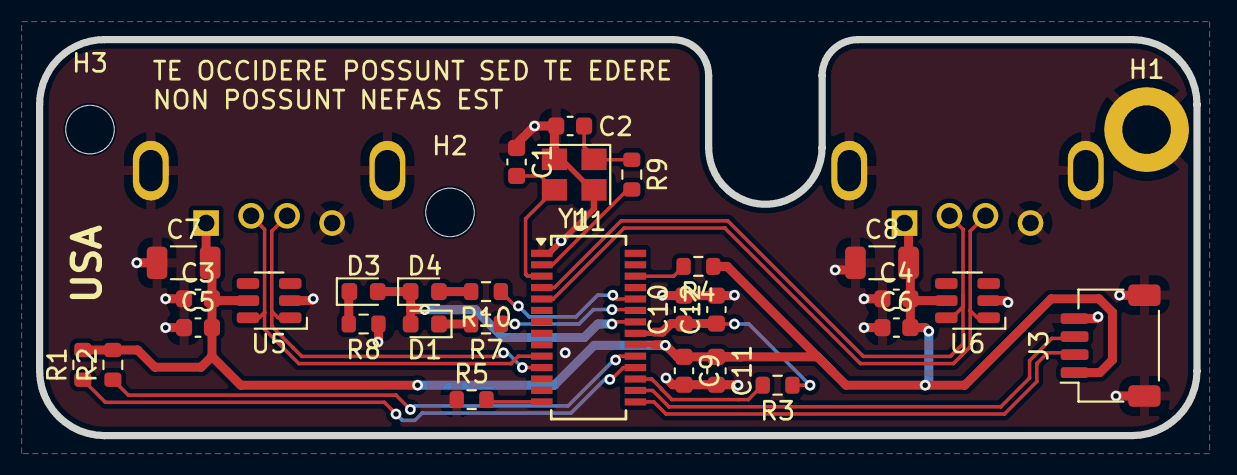
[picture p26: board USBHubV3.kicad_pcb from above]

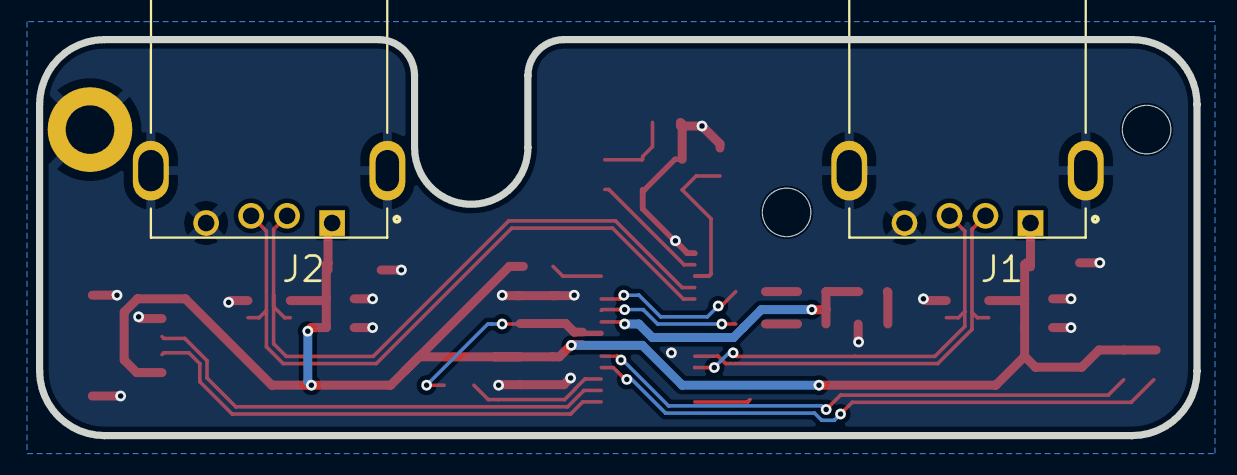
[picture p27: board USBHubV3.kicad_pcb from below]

Board: 2 copper layers, 64.3 x 22.0 mm, 34 parts (2 on the bottom side), 23 nets.

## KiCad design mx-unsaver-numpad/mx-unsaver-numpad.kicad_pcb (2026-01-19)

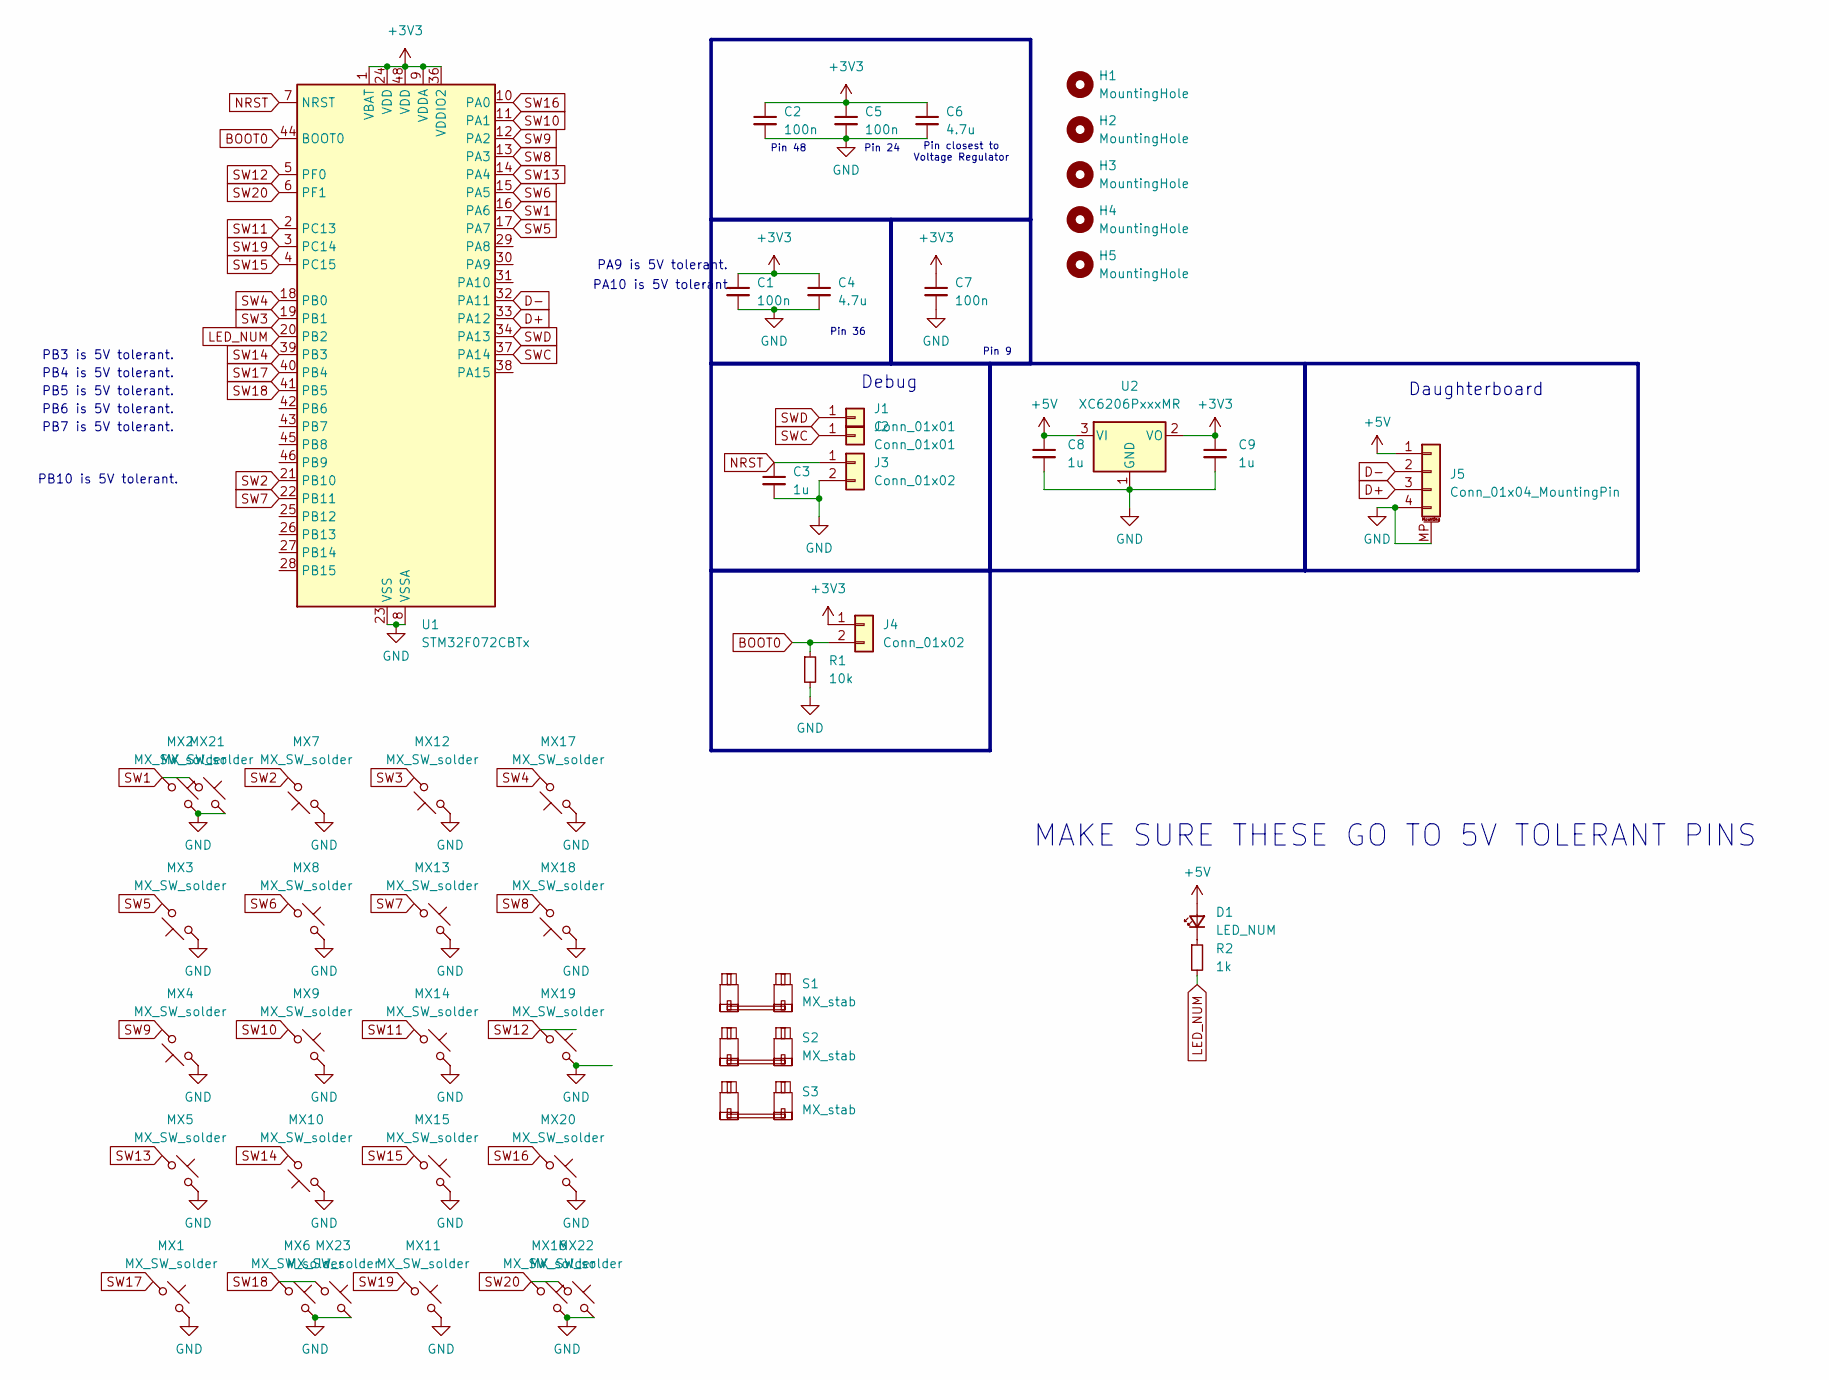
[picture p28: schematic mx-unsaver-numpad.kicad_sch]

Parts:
C1, C2, C5, C7: 100n; C_0603_1608Metric; Digikey 311-1088-1-ND
C3, C8, C9: 1u; C_0805_2012Metric; Digikey 1276-1029-1-ND
C4, C6: 4.7u; C_0603_1608Metric; Digikey 1276-1784-1-ND
D1: LED_NUM; LED_MX_3mm_Offset_Flipped; Digikey 67-1058-ND
H1, H2, H3, H4: MountingHole; MountingHole_2.7mm_M2.5
H5: MountingHole; HOLE_BackSpace_Slots
J1, J2: Conn_01x01; PinHeader_1x01_P2.54mm
J3, J4: Conn_01x02; PinHeader_1x02_P2.54mm_BOOT
J5: Conn_01x04_MountingPin; JST_SH_SM04B-SRSS-TB_1x04-1MP_P1.00mm_Horizontal; Digikey 455-SM04B-SRSS-TBCT-ND
MX1, MX3, MX4, MX5, MX6, MX7, MX9, MX10, MX11, MX12, MX13, MX14, MX15, MX16, MX17, MX18, MX19, MX20, MX22, MX23: MX_SW_solder; SW_MX_1u_PCBMount
MX2: MX_SW_solder; SW_MX_1u_PCBMount_NoRight
MX8: MX_SW_solder; SW_MX_1u_PCBMount_NoLeft
MX21: MX_SW_solder; SW_MX_1u_3pin
R1: 10k; R_0805_2012Metric; Digikey RMCF0805FT10K0CT-ND
R2: 1k; R_0805_2012Metric; Digikey P1.0KDACT-ND
S1, S2, S3: MX_stab; STAB_MX_2u_FixedDistance
U1: STM32F072CBTx; LQFP-48_7x7mm_P0.5mm
U2: XC6206PxxxMR; SOT-23-3; Digikey 893-XC6206P332MR-GCT-ND

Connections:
+3V3: C1.1, C2.1, C4.1, C5.1, C6.1, C7.1, C9.1, J4.1, U1.1 (VBAT), U1.9 (VDDA), U1.24 (VDD), U1.36 (VDDIO2), U1.48 (VDD), U2.2 (VO)
+5V: C8.1, D1.2 (A), J5.1, U2.3 (VI)
BOOT0: J4.2, R1.1, U1.44 (BOOT0)
D+: J5.3, U1.33 (PA12)
D-: J5.2, U1.32 (PA11)
GND: C1.2, C2.2, C3.2, C4.2, C5.2, C6.2, C7.2, C8.2, C9.2, J3.2, J5.4, J5.MP (MountPin), MX1.2, MX2.2, MX3.1, MX4.1, MX5.2, MX6.2, MX7.1, MX8.2, MX9.2, MX10.1, MX11.2, MX12.1, MX13.2, MX14.2, MX15.2, MX16.2, MX17.1, MX18.1, MX19.2, MX20.2, MX21.2, MX22.2, MX23.2, R1.2, U1.8 (VSSA), U1.23 (VSS), U1.35 (VSS), U1.47 (VSS), U2.1 (GND)
LED_NUM: R2.2, U1.20 (PB2)
NRST: C3.1, J3.1, U1.7 (NRST)
unnamed: D1.1 (K), R2.1
SW1: MX2.1, MX21.1, U1.16 (PA6)
SW2: MX7.2, U1.21 (PB10)
SW3: MX12.2, U1.19 (PB1)
SW4: MX17.2, U1.18 (PB0)
SW5: MX3.2, U1.17 (PA7)
SW6: MX8.1, U1.15 (PA5)
SW7: MX13.1, U1.22 (PB11)
SW8: MX18.2, U1.13 (PA3)
SW9: MX4.2, U1.12 (PA2)
SW10: MX9.1, U1.11 (PA1)
SW11: MX14.1, U1.2 (PC13)
SW12: MX19.1, U1.5 (PF0)
SW13: MX5.1, U1.14 (PA4)
SW14: MX10.2, U1.39 (PB3)
SW15: MX15.1, U1.4 (PC15)
SW16: MX20.1, U1.10 (PA0)
SW17: MX1.1, U1.40 (PB4)
SW18: MX6.1, MX23.1, U1.41 (PB5)
SW19: MX11.1, U1.3 (PC14)
SW20: MX16.1, MX22.1, U1.6 (PF1)
SWC: J2.1, U1.37 (PA14)
SWD: J1.1, U1.34 (PA13)

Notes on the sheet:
PA10 is 5V tolerant.
MAKE SURE THESE GO TO 5V TOLERANT PINS
PB10 is 5V tolerant.
Pin 24
PB6 is 5V tolerant.
Debug
Pin 48
Pin 36
PB5 is 5V tolerant.
PB3 is 5V tolerant.
Pin 9
Daughterboard
Pin closest to Voltage Regulator
PB4 is 5V tolerant.
PB7 is 5V tolerant.
PA9 is 5V tolerant.

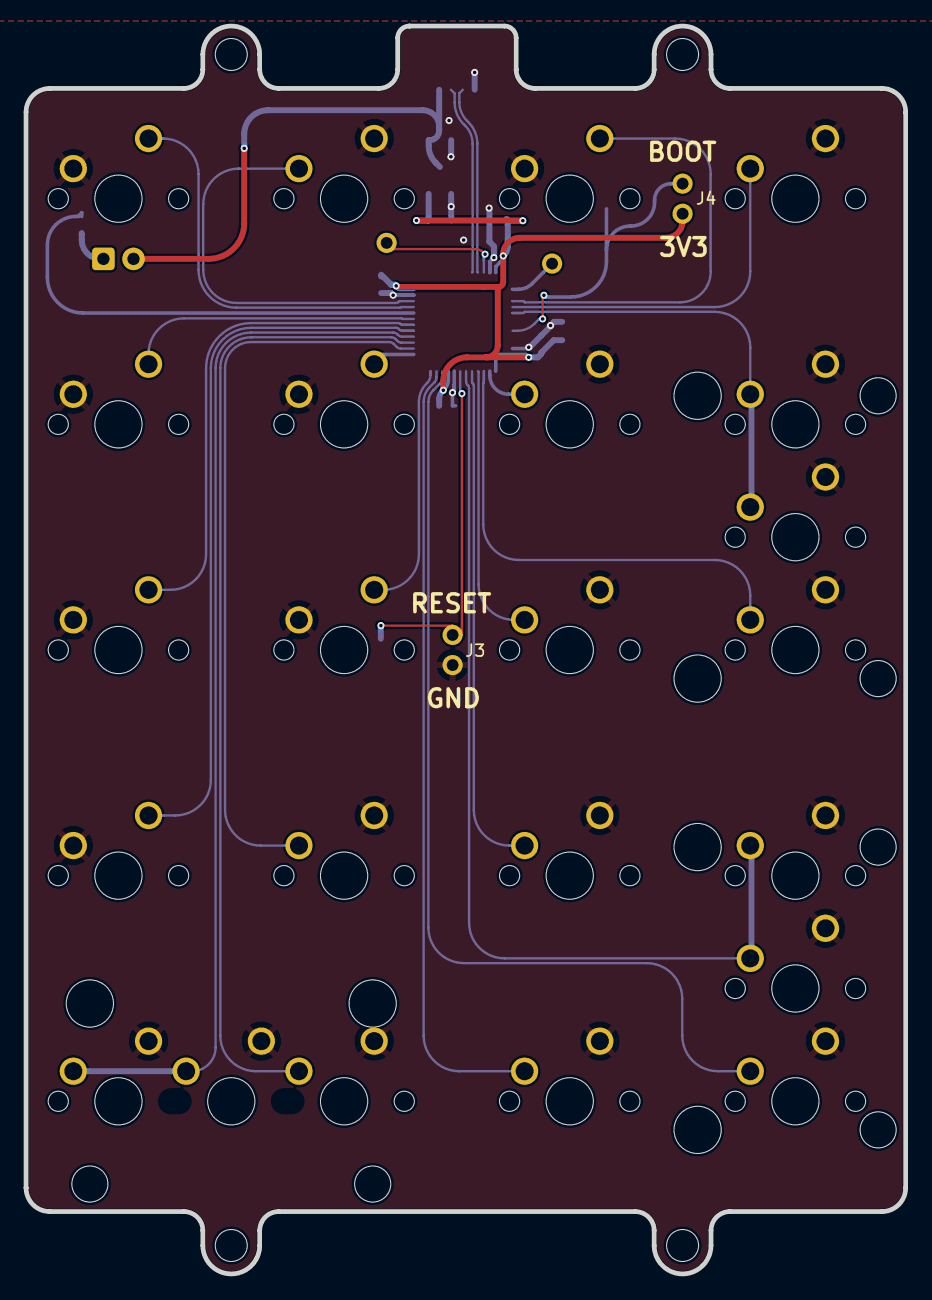
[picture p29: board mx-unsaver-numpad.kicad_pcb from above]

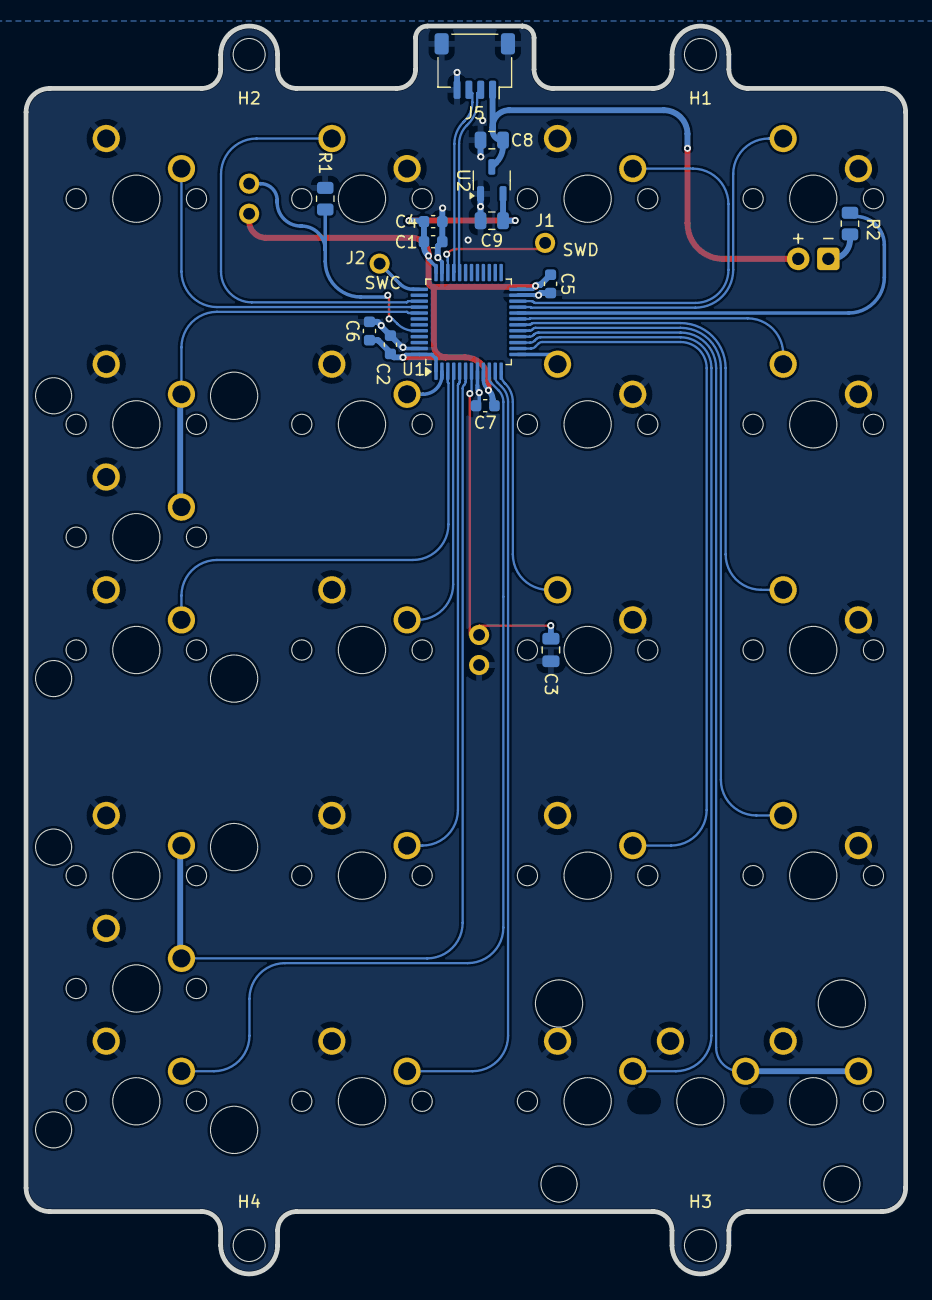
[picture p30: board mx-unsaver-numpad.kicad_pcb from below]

Board: 2 copper layers, 74.3 x 105.3 mm, 50 parts (21 on the bottom side), 31 nets.

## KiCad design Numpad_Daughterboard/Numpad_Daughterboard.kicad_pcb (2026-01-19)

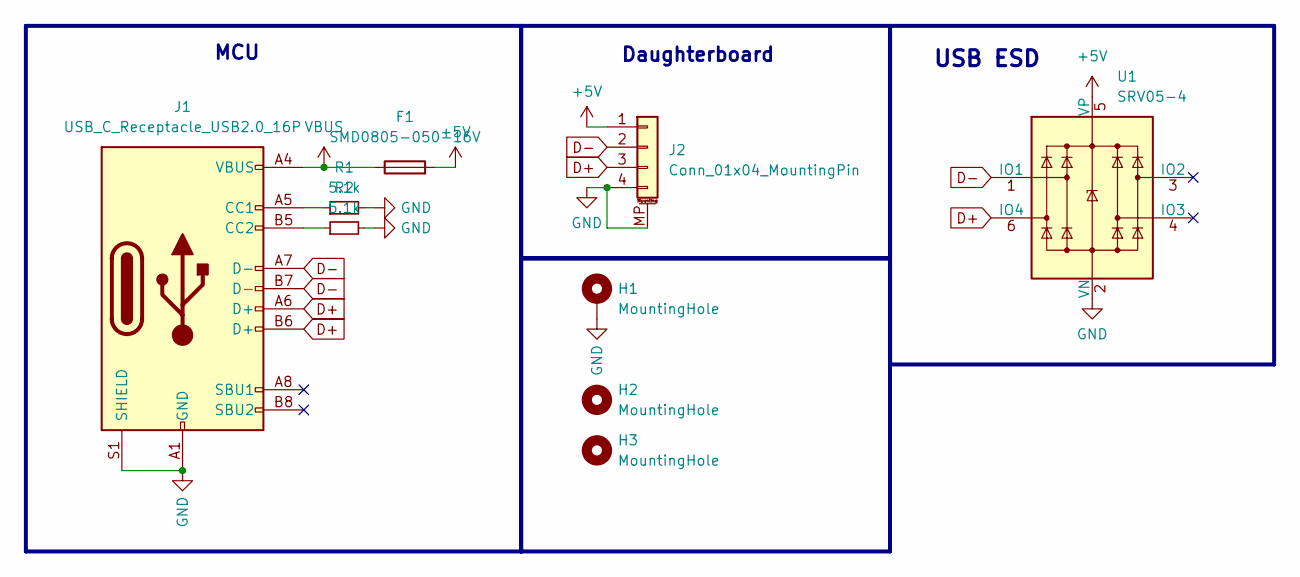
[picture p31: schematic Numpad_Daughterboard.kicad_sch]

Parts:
F1: SMD0805-050-16V; Fuse_1206_3216Metric; Manufacturer Part Number SMD0805-050-16V; LCSC Part Number C2833485
H1: MountingHole; MountingHole_2.5mm_Pad
H2, H3: MountingHole; MountingHole_2.7mm_M2.5
J1: USB_C_Receptacle_USB2.0_16P; PHOENIX_1332645; Digikey 277-1332645CT-ND
J2: Conn_01x04_MountingPin; JST_SH_SM04B-SRSS-TB_1x04-1MP_P1.00mm_Horizontal; Digikey 455-SM04B-SRSS-TBCT-ND
R1, R2: 5.1k; C_0603_1608Metric_Pad1.08x0.95mm_HandSolder; Digikey P5.10KHCT-ND
U1: SRV05-4; SOT-23-6-routable; Digikey 5399-SRV05-4CT-ND

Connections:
+5V: F1.2, J2.1, U1.5 (VP)
D+: J1.A6 (D+), J1.B6 (D+), J2.3, U1.6 (IO4)
D-: J1.A7 (D-), J1.B7 (D-), J2.2, U1.1 (IO1)
GND: H1.1, J1.A1 (GND), J1.A12 (GND), J1.B1 (GND), J1.B12 (GND), J1.S1 (SHIELD), J2.4, J2.MP (MountPin), R1.2, R2.2, U1.2 (VN)
unnamed: J1.A5 (CC1), R1.1
unnamed: J1.B5 (CC2), R2.1
VBUS: F1.1, J1.A4 (VBUS), J1.A9 (VBUS), J1.B4 (VBUS), J1.B9 (VBUS)

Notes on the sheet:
MCU
USB ESD
Daughterboard

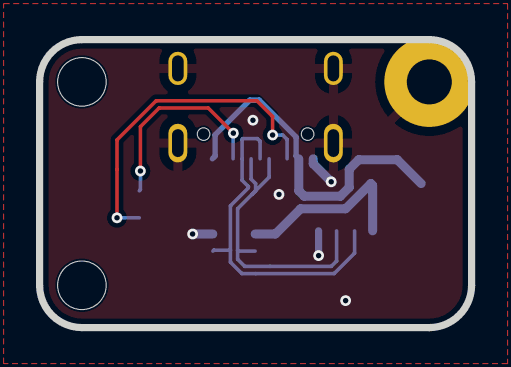
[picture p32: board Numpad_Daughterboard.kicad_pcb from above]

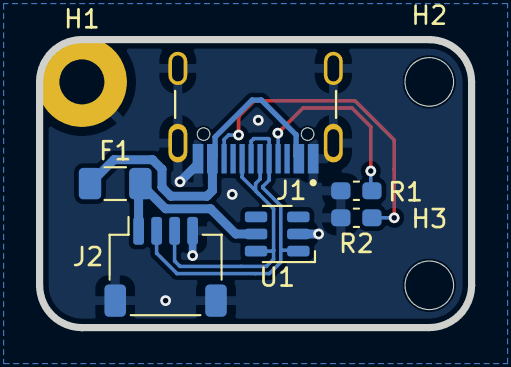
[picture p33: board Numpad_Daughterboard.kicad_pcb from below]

Board: 2 copper layers, 24.0 x 16.0 mm, 9 parts (9 on the bottom side), 7 nets.

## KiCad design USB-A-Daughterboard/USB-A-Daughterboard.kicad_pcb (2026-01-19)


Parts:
C1, C2: 33p; C_0603_1608Metric; Digikey 1276-1070-1-ND
C3, C4, C11, C12, C13: 100n; C_0603_1608Metric; Digikey 311-1088-1-ND
C5, C6: 10u; C_0603_1608Metric; Digikey 1276-1192-1-ND
C7, C8: 100u; C_1206_3216Metric; Digikey 490-GRM31CR60J107KEA8LCT-ND
C9, C10: 1u; C_0603_1608Metric; Digikey 1276-6524-1-ND
D1, D2, D3, D4: LED_Small; LED_0603_1608Metric; Digikey 2007-BL-HJC36G-AV-TRBCT-ND
F1: SMD0805-050-16V; Fuse_1206_3216Metric; Manufacturer Part Number SMD0805-050-16V; LCSC Part Number C2833485
H1: MountingHole; MountingHole_2.7mm_M2.5_DIN965_Pad
H2, H3, H4, H5: MountingHole; MountingHole_2.7mm_M2.5
J1, J2, J5: USB_C_Receptacle_USB2.0_16P; PHOENIX_1332645; Digikey 277-1332645CT-ND
J3, J4: Conn_01x04; JST_SH_SM04B-SRSS-TB_1x04-1MP_P1.00mm_Horizontal; Digikey 455-SM04B-SRSS-TBCT-ND
R1: 2.7k; R_0603_1608Metric; Digikey RMCF0603FT2K70
R2, R3, R4, R5, R10: 10k; R_0603_1608Metric; Digikey 311-10.0KHRCT-ND
R6, R7, R9: 510; R_0603_1608Metric; Digikey RR08P510DCT-ND
R8: 1k; R_0603_1608Metric; Digikey RMCF0603FT1K00CT-ND
R11, R12: 33k; R_0603_1608Metric; Digikey 311-33.0KHRCT-ND
R13, R14: 5.1k; R_0603_1608Metric; Digikey P5.10KHCT-ND
R15, R16, R17, R18: 56k; R_0603_1608Metric; Digikey P56KGCT-ND
TP1, TP2, TP3: TestPoint_Small; TestPoint_THTPad_D1.0mm_Drill0.5mm
U1: FE1.1s-BSOP28BCN; SSOP-28_3.9x9.9mm_P0.635mm
U2, U3, U4, U5, U6: SRV05-4; SOT-23-6-routable; Digikey 5399-SRV05-4CT-ND
U7: TPS2552DBVR; SOT-23-6; LCSC C46506
Y1: Crystal_GND24; Crystal_SMD_3225-4Pin_3.2x2.5mm; Digikey XC1810CT-ND

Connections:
+3.3V: C10.1, C12.1, R5.1, U1.21 (VDD3F)
+5V: C9.1, C11.1, C13.2, F1.2, R2.1, R3.2, R4.2, R10.1, U1.20 (VDD5), U6.5 (VP), U7.1 (VIN)
+5V_lim: C3.2, C4.2, C5.2, C6.2, C7.2, C8.2, J1.A4 (VBUS), J1.A9 (VBUS), J1.B4 (VBUS), J1.B9 (VBUS), J2.A4 (VBUS), J2.A9 (VBUS), J2.B4 (VBUS), J2.B9 (VBUS), J3.1, J4.1, R15.2, R16.2, R17.2, R18.2, TP3.1, U2.5 (VP), U3.5 (VP), U4.5 (VP), U5.5 (VP), U7.6 (VOUT)
D0+: J5.A6 (D+), J5.B6 (D+), U1.16 (DPU), U6.1 (IO1)
D0-: J5.A7 (D-), J5.B7 (D-), U1.15 (DMU), U6.6 (IO4)
D1+: J4.3, U1.11 (DP1), U5.1 (IO1)
D1-: J4.2, U1.10 (DM1), U5.6 (IO4)
D2+: J3.3, U1.9 (DP2), U4.1 (IO1)
D2-: J3.2, U1.8 (DM2), U4.6 (IO4)
D3+: J1.A6 (D+), J1.B6 (D+), U1.7 (DP3), U2.1 (IO1)
D3-: J1.A7 (D-), J1.B7 (D-), U1.6 (DM3), U2.6 (IO4)
D4+: J2.A6 (D+), J2.B6 (D+), U1.5 (DP4), U3.1 (IO1)
D4-: J2.A7 (D-), J2.B7 (D-), U1.4 (DM4), U3.6 (IO4)
DRV: D1.2 (A), D2.2 (A), D3.1 (K), D4.1 (K), U1.22 (DRV)
FAULT: R10.2, TP2.1, U1.26 (~OVCJ), U7.4 (~FAULT)
GND: C1.1, C2.1, C3.1, C4.1, C5.1, C6.1, C7.1, C8.1, C9.2, C10.2, C11.2, C12.2, C13.1, H1.1, J1.A1 (GND), J1.A12 (GND), J1.B1 (GND), J1.B12 (GND), J1.S1 (SHIELD), J2.A1 (GND), J2.A12 (GND), J2.B1 (GND), J2.B12 (GND), J2.S1 (SHIELD), J3.4, J3.MP (MountPin), J4.4, J4.MP (MountPin), J5.A1 (GND), J5.A12 (GND), J5.B1 (GND), J5.B12 (GND), J5.S1 (SHIELD), R1.1, R7.1, R12.2, R13.2, R14.2, U1.1 (VSS), U2.2 (VN), U3.2 (VN), U4.2 (VN), U5.2 (VN), U6.2 (VN), U7.2 (GND), Y1.2, Y1.4
LED1: R6.1, U1.23 (LED1)
LED2: R9.1, U1.24 (LED2)
unnamed: C2.2, R8.1, Y1.1
unnamed: D1.1 (K), D4.2 (A), R6.2
unnamed: D2.1 (K), R7.2
unnamed: D3.2 (A), R9.2
unnamed: J1.A5 (CC1), R15.1
unnamed: J1.B5 (CC2), R16.1
unnamed: J2.A5 (CC1), R17.1
unnamed: J2.B5 (CC2), R18.1
unnamed: J5.A5 (CC1), R13.1
unnamed: J5.B5 (CC2), R14.1
unnamed: R11.2, R12.1
unnamed: R3.1, U1.19 (BUSJ)
unnamed: R1.2, U1.14 (REXT)
unnamed: R4.1, U1.18 (VBUSM)
unnamed: R5.2, U1.17 (~XRSTJ)
unnamed: R11.1, U7.5 (ILIM)
P_EN: R2.2, TP1.1, U1.25 (~PWRJ), U7.3 (~EN)
VBUS: F1.1, J5.A4 (VBUS), J5.A9 (VBUS), J5.B4 (VBUS), J5.B9 (VBUS)
XIN: C1.2, U1.3 (XIN), Y1.3
XOUT: R8.2, U1.2 (XOUT)

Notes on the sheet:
Upstream 0 USB-C
FE1.1s
C3 and C6 near pin 20
C4 and C5 near pin 21
Downstream 1 JST
Test Points
Crystal
Decoupling
(from 2nd HUB)
Downstream 3 ESD
Downstream 4
(from keyboard)
Downstream 4 ESD
Needs to be +- 1%
Downstream 2 ESD
FE1.1s has integrated series resistors.
LEDs
Downstream 1 ESD
Current Limiter
Downstream 2 JST
Downstream 3
Upstream 0 ESD



Board: 2 copper layers, 96.1 x 29.3 mm, 57 parts (57 on the bottom side), 38 nets.
